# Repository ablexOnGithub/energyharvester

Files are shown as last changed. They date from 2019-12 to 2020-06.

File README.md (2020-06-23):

# lorawan_eharvester_node
hardware and code artefacts of lorawan energy harvester node

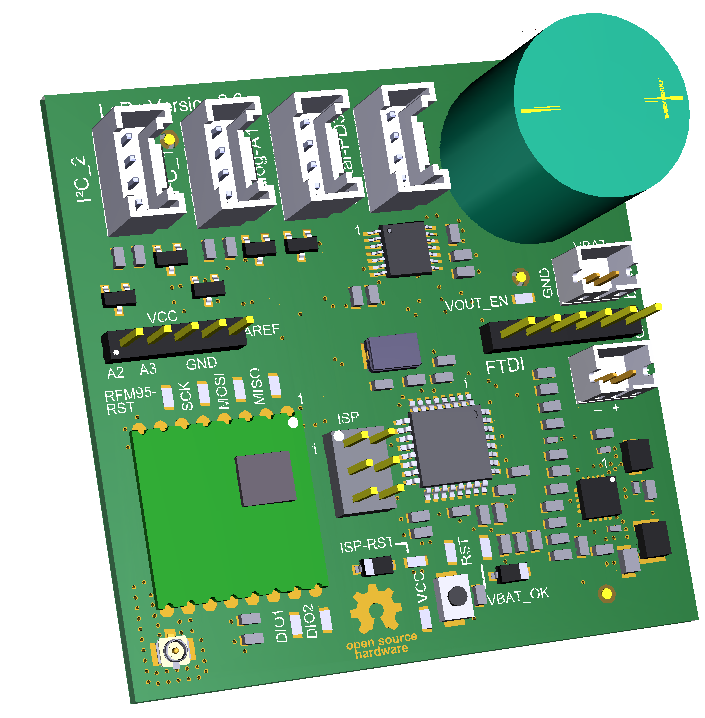
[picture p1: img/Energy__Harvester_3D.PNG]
3D view of harvester PCB


## Technical features
* AVR ATmega328PB
* RFM95 LoRaWAN-Modul 868MHz (replaceable with other market variants)
* TI BQ25570 Energy Harvester with MPPT, configured for solar power source
* 1F Supercap
* 2x Grove I2C sockets
* 1x Grove Analog socket
* 1x Grove Digital socket
* 1x JST PH socket for battery connection
* 1x JST PH socket for solar panel connection
* 1x FTDI connector for serial console and programming
* 1x u.FL socket for LoRa antenna
* Power supply can be configured for different battery types (LiPo, LiFePo or similar)
* Switchable Vcc for Grove connectors through CMOS switches
* ISP socket for AVR programming

## Sensor connections
In general all sensor sockets (Grove layout) have a switchable Vcc line. It is off by default and has to be enabled by corresponding GPIO lines.

## I2C
There are 2 hardware I2C ports in the 328PB. Arduino currently supports one out of the box (running as a 328P Arduino Pro Mini clone). The second I2C port is prepared for future use.

### Grove I2C 01
The SDA and SCL lines of the socket are connected to PC4 and PC5 accordingly.

__GPIO PD4 == High (1) activates Vcc__

When activating Vcc, additionally SDA and SCL are pulled high to Vcc via 10 kOhm resistors. 

### Grove I2C 02
The SDA1 and SCL1 lines of the socket are connected to PE0 and PE1 accordingly.

__GPIO PD5 == High (1) activates Vcc__

When activating Vcc, additionally SDA1 and SCL1 are pulled high to Vcc via 10 kOhm resistors.

## Grove Analog
The analog signal connected to the socket is fed into the ADC1 input of the AVR.

__GPIO PD6 == High (1) activates Vcc__

## Grove Digital
Vcc on the digital Grove socket is permanently supplied.

__GPIO PD3 == Data input for digital sensor__

## Energy harvesting power supply
The Energy Harvester integrates a harvesting power supply chip BQ25570 from Texas Instruments. It provides the 3.3V Vcc supply voltage for the AVR and attached sensors. It also provides the charging voltage for the batteries and the supercap. It also features MPPT (Maximum Power Point Tracking), to extract maximum energy from solar panels even in low light scenarios. Other power sources like thermal energy generators (TEG) can also be adapted as power source. 5.5V is the maximum allowed charge voltage level of the BQ25570. And the maximum input voltage of the power source is 5.1V. The allowed peak input power is 510mW, thus a solar cell for this energy harvester should be selected accordingly and cells > 0.5W seem not to be feasible. A better approach would be to use two 0.25W cells in parallel to adapt to the sun path by pointing into different directions. Then, bypass diodes might have to added to the solar cells.

Product page:
http://www.ti.com/product/BQ25570

## Configuration of battery type

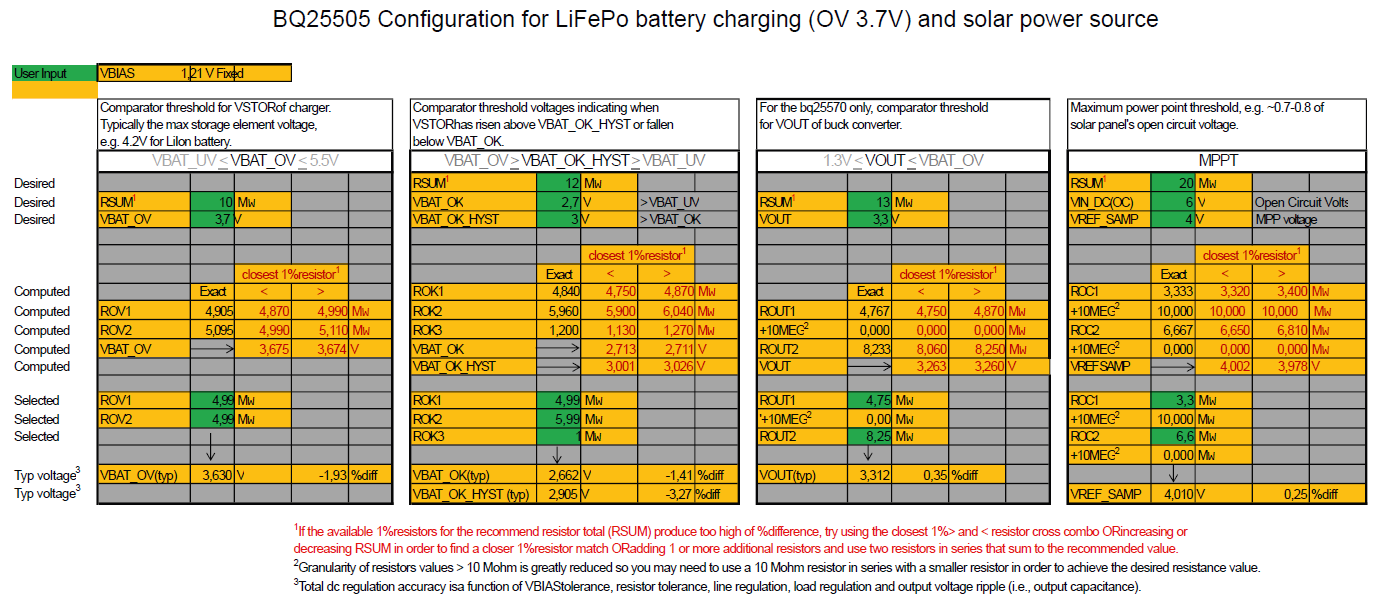
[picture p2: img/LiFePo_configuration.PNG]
Example of resistor configuration sheet


The image shows a resistor configuration sheet (example of LiFePo configuration), provided as a template by Texas Instruments. The sheet references the predecessor BQ25505, which provides the same configuration system with multiple resistors. All resistors are 1% 1/10W SMD parts in size 0603.

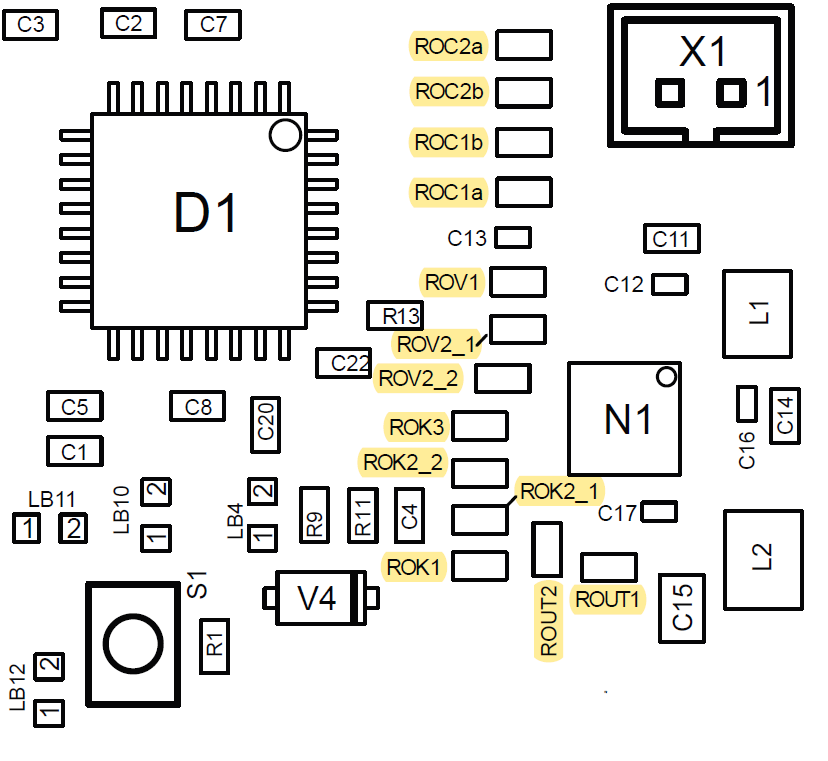
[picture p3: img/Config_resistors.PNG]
Location of configuration resistors on PCB


To configure the harvester for LiPo or LiFePo battery cells the corresponding resistors have to have the following values. This mainly adjusts the overvoltage level.

__Info for Supercap mode:__ I'm currently trying out a Vishay supercap with 90F capacity at 5V. This will not have a backup battery. Idea is to increase overvoltage level to 5V (instead of 4.2/3.6V), to have more headroom for the Buck converter to longer provide 3.3V to the sensor electronics. Hopefully this is a solution for sensors that really need stable 3.3V supply. The LiPo/LiFePo configurations are running until below 3V. This currently is an untested resistor configuration!!! 

Part 	| Li-Po cells | LiFePo cells	| Supercap mode 
--- | ---	| ---	| ---
ROK1 	| 4.99 MOhm	| 4.99 MOhm	| 4.22 MOhm
ROK2_1	| 3.3 MOhm	| 4.99 MOhm	| 4.02 MOhm
ROK2_2	| 4.02 MOhm	| 1 MOhm	| 3.3 MOhm
ROK3 	| 806 kOhm	| 1 MOhm	| 681 kOhm
ROV1	| 5.62 MOhm	| 4.99 MOhm	| 3.6 MOhm
ROV2_1	| 4.02 MOhm	| 4.02 MOhm	| 3.0 MOhm
ROV2_2  | 3.3 MOhm	| 1 MOhm	| 3.3 MOhm
ROC1a 	| 3.3 MOhm	| 3.3 MOhm	| 3.3 MOhm
ROC1b 	| 10 MOhm	| 10 MOhm	| 10 MOhm
ROC2a	| 1 MOhm	| 1 MOhm	| 1 MOhm
ROC2b 	| 5.6 MOhm	| 5.6 MOhm	| 5.6 MOhm

## Tracking of Vcc
Using a voltage divider Vcc is measured against the AVR internal reference voltage (1.1V, selected via Software, AVR reference "INTERNAL"). The corresponding voltage is fed into ADC0 of the AVR, to allow for a dynamic adjustment of the sleep interval, related to the actual Vcc voltage level. The lower Vcc the longer the sleep intervall to safe power. Vcc can only be measured, while analog Grove port is activated by __GPIO PD6 == High__.

# PCB Bring Up

## Test of Boost function
* Connect a 3V to 4V power supply with the solar connector X1, simulation a solar cell.
* Measure the open circuit voltage at the battery connector X2, which shall be the configured Overvoltage level
* After connecting a power supply it may take about 1 minute to charge the 1F supercap to the corresponding voltage level 4.2V, 3.6V or 5V
* Now connect a battery or a supercap, depending on build variant, that is compatible to the measured voltage level

## Test of Buck function
* Set __VOUT_EN__ active by bridging the corresponding jumper pads
* Measure voltage Vcc at 5-pin header and expect to see ca. 3.3V 
                                                                                                                        
## Programming of Arduino bootloader
* Set __VCC__ active by bridging the corresponding jumper pads
* Set __ISP_RST__ active by bridging the corresponding jumper pads
* Connect the ISP adapter (z.B. ATMEL  JTAGICE3) with the programming port
* Program a matching Arduino bootloader into the AVR     

## Fuse Bits

After programming the bootloader, we have to set the fuse bits to match the hardware features.

Fuse | Value
--- | ---
CFD | "CFD_DISABLED"
BODLEVEL | "DISABLED"
RSTDISBL | unset
DWEN | unset
SPIEN | set
WDTON | unset
EESAVE | set
BOOTSZ | "256W_3F00"
BOOTRST | set
CKDIV8 | unset
CKOUT | unset
SUT_CKSEL | "EXTXOSC_8MHZ_XX_16KCK_14CK_65MS"

These flags evaluate to the following bit masks:

__EXTENDED__= 0xF7
__HIGH__	= 0xD6
__LOW__		= 0xFF             

## Enable Reset lines
* Set __RESET__ active by bridging the corresponding jumper pads
	* This enables reset per switch and Arduino serial adapter (e.g. FTDI USB2COM)
* Set __VBAT_OK__ active by bridging the corresponding jumper pads
	* This enables reset by power good signal from bq25570 going low in case of battery undervoltage
 
## Test of serial connection 
* Connect a serial adapter
* Compile and download a simple Arduino sketch for the 328PB and check for valid debug output in serial console of Arduino
* This checks for a working serial port and a functioning bootloader

## Connecting RFM95 I/O
Bridge the remaining jumper pads for the LoRa module, which are __RFM95-RST__, __MISO__, __MOSI__, __SCK__, __DIO1__ and __DIO2__.

Now you can adjust the supplied test sketch in the ```/src``` folder by adding valid keys for your TTN application into, compile and download it to the harvester. In the serial console you will find debug output after restart, giving information on the LoRaWAN communication.

# Software

## Configuration of Arduino IDE
Avrdude has to be configured to ignore the changed chip ID of the AVR ATMega328PB when uploading a new Arduino sketch. This is done by adding a '-F' to the command line options of verbose mode for avrdude in Arduino's __platform.txt__ document. There are two lines to edit. After this activate "verbose"
mode for upload in the Arduino IDE preferences.
```
tools.avrdude.upload.params.verbose=-v -F
tools.avrdude.program.params.verbose=-v -F
```
### Libraries from Library manager inside Arduino IDE
The following libraries are needed to use the provided template sketch
* Low-Power by Rocket Scream Electronics (there are alot others with a similar name, please take this one)
* MCCI LoRaWAN lmic Library (tested with v3.0.99, currently the MCCI lmic version is the newest fork)

### Additional libraries
https://github.com/felias-fogg/SoftI2CMaster

### Board selection
Install the Arduino AVR Boards package and select __"Arduino Pro or Pro mini"__ as board. As processor select __"ATmega 328p (3.3V, 8MHz)"__. Now connect your FTDI TTL serial port and configure the port inside the IDE accordingly.                     

## Example sketch for Arduino
The example sketch soil_humidity_sensor_template.ino in the /src folder presents a template for building a first prototype of the Energy Harvester with a capacitive soil humidity sensor attached.

### Device and App configuration

# Energy sources

## Solar cells

### crystaline solar cells

### thin film solar cells

# Measurements

## Run and Sleep current
I made some test measurements with a Qoitech Otii source meter for sleep current of the energy harvester. These first measurements were done without attached external sensors, to see the theoretical minimum consumption of the node. It was measured at the battery port of the harvester and the supply was set to 3.2V, to simulate a LiFePo battery.

This is a recording of the system startup showing all power modes of the device. The peak current seems to be slightly above 60mA

Startup measurement of power consumption

A zoomed view of sleep current. The internal power consumption of the BQ25570 seems to be visible here. We got a __mean value of 3.9uA__ and a __maximum value of 30.1uA__ sleep current.

Zoom on sleep current

An even more detailed look into the energy consumption of the device when it wakes __every 8s__ and going to sleep directly again. 8s is the longest possible sleep duration of the AVR internal sleep timer. So every longer sleep period has to be implemented with a sequence of a multiple of 8s sleeps. The ingrease of energy consumption for this "useless" sleep/wakeup is about __2.36nWh per iteration__.

If you plan to use an external RTC to allow for longer sleep times and interrupt driven wake up, check if you RTC consumes less than the energy needed by a sequence of multiple 8s wake ups.

Energy consumption per wake up

# 3D printed parts
There are also 3D print parts that help mounting the harvester in rugged outdoor housings
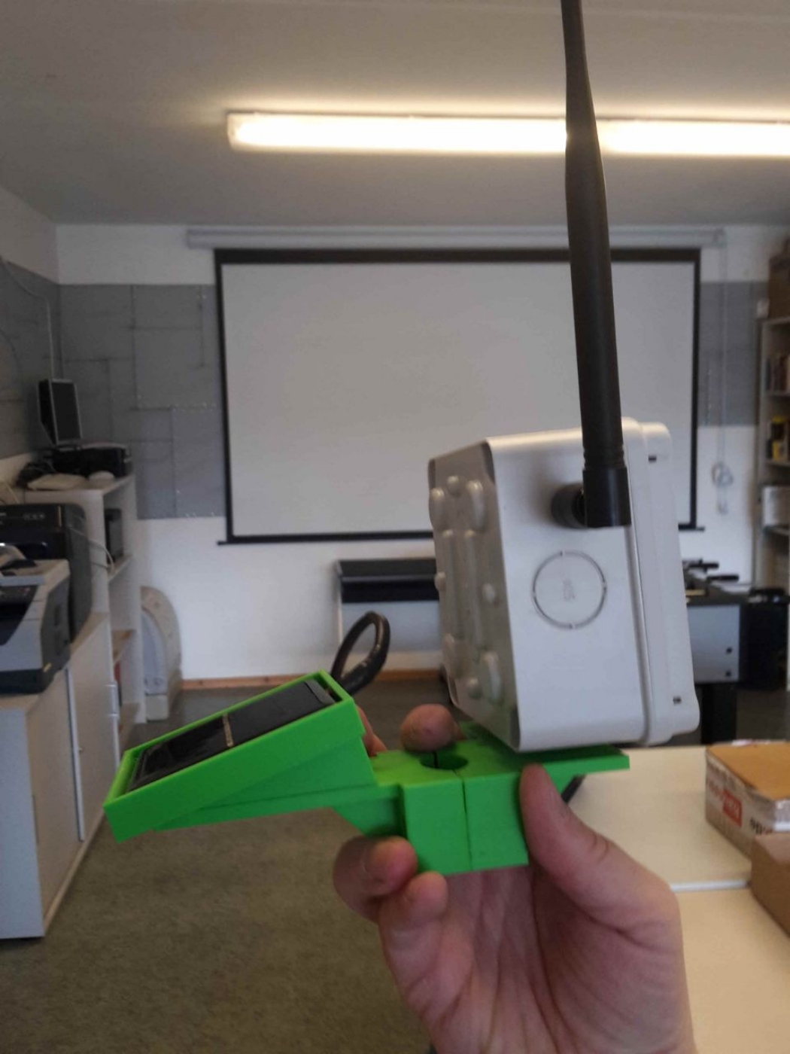
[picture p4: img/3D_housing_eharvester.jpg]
eharvester mount for outdoor housings


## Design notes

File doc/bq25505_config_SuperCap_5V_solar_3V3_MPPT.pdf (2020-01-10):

User Input | VBIAS | 1,21 | V
Fixed
Comparator threshold for VSTOR of charger. | Comparator threshold voltages indicating when | For the bq25570 only, comparator threshold | Maximum power point threshold, e.g. ~0.7-0.8 of
Typically the max storage element voltage, | VSTOR has risen above VBAT_OK_HYST or fallen | for VOUT of buck converter. | solar panel's open circuit voltage.
e.g. 4.2V for LiIon battery. | below VBAT_OK.
Desired | RSUM¹ | 12 | MW | RSUM¹ | 20 | MW
Desired | RSUM¹ | 10 | MW | VBAT_OK | 3,3 | V | > VBAT_UV | RSUM¹ | 13 | MW | VIN_DC(OC) | 6 | V | Open Circuit Volts
Desired | VBAT_OV | 5 | V | VBAT_OK_HYST | 3,5 | V | > VBAT_OK | VOUT | 3,3 | V | VREF_SAMP | 4 | V | MPP voltage
| | | | | | | Exact | < | > | | | | | | | | Exact | < | >
Computed | | Exact | < | > | | ROK1 | 4,149 | 4,120 | 4,220 | MW | | Exact | < | > | | ROC1 | 3,333 | 3,320 | 3,400 | MW
Computed | ROV1 | 3,630 | 3,570 | 3,650 | MW | ROK2 | 7,166 | 7,150 | 7,320 | MW | ROUT1 | 4,767 | 4,750 | 4,870 | MW | +10MEG² | 10,000 | 10,000 | 10,000 | MW
Computed | ROV2 | 6,370 | 6,340 | 6,490 | MW | ROK3 | 0,686 | 0,681 | 0,698 | MW | +10MEG² | 0,000 | 0,000 | 0,000 | MW | ROC2 | 6,667 | 6,650 | 6,810 | MW
Computed | VBAT_OV | | 5,038 | 5,042 | V | VBAT_OK | | 3,310 | 3,309 | V | ROUT2 | 8,233 | 8,060 | 8,250 | MW | +10MEG² | 0,000 | 0,000 | 0,000 | MW
Computed | | | | | | VBAT_OK_HYST | | 3,510 | 3,509 | V | VOUT | | 3,263 | 3,260 | V | VREF SAMP | | 4,002 | 3,978 | V
Selected | ROV1 | 3,6 | MW | ROK1 | 4,22 | MW | ROUT1 | 4,75 | MW | ROC1 | 3,3 | MW
Selected | ROV2 | 6,3 | MW | ROK2 | 7,32 | MW | '+10MEG² | 0,00 | MW | +10MEG² | 10,000 | MW
Selected | ROK3 | 0,681 | MW | ROUT2 | 8,25 | MW | ROC2 | 6,6 | MW
| | | | | | | | | | | | | | | | +10MEG² | 0,000 | MW
Typ voltage³ | VBAT_OV(typ) | 4,991 | V | -0,18 | % diff | VBAT_OK (typ) | 3,309 | V | 0,27 | % diff | VOUT(typ) | 3,312 | 0,35 | % diff
Typ voltage³ | VBAT_OK_HYST (typ) | 3,504 | V | 0,12 | % diff | VREF_SAMP | 4,010 | V | 0,25 | % diff

1
If the available 1% resistors for the recommend resistor total (RSUM) produce too high of % difference, try using the closest 1% > and < resistor cross combo OR increasing or decreasing RSUM in order to find a closer 1% resistor match OR adding 1 or more additional resistors and use two resistors in series that sum to the recommended value.
2Granularity of resistors values > 10 Mohm is greatly reduced so you may need to use a 10 Mohm resistor in series with a smaller resistor in order to achieve the desired resistance value.

3
Total dc regulation accuracy is a function of VBIAS tolerance, resistor tolerance, line regulation, load regulation and output voltage ripple (i.e., output capacitance).
VBAT_UV < VBAT_OV < 5.5V | VBAT_OV > VBAT_OK_HYST > VBAT_UV | 1.3V < VOUT < VBAT_OV | MPPT

closest 1% resistor¹

closest 1% resistor¹

closest 1% resistor¹

closest 1% resistor¹

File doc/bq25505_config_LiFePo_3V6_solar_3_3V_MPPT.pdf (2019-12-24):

User Input | VBIAS | 1,21 V Fixed
Comparator threshold for VSTORof charger. | Comparator threshold voltages indicating when | For the bq25570 only, comparator threshold | Maximum power point threshold, e.g. ~0.7-0.8 of
Typically the max storage element voltage, | VSTORhas risen above VBAT_OK_HYST or fallen | for VOUT of buck converter. | solar panel's open circuit voltage.
e.g. 4.2V for LiIon battery. | below VBAT_OK.
Desired | | | RSUM¹
12 | MW | RSUM¹
20 | MW
Desired | RSUM¹
10 | MW | VBAT_OK | 2,7 | V | >VBAT_UV | RSUM¹
13 | MW | VIN_DC(OC) | 6 | V | Open Circuit Volts
Desired | VBAT_OV | 3,7 V | VBAT_OK_HYST | 3 V | > VBAT_OK | VOUT | 3,3 V | VREF_SAMP | 4 V | MPP voltage
Exact | < | > | Exact | < | >
Computed | Exact | < | > | ROK1 | 4,840 | 4,750 | 4,870 | MW | Exact | < | > | ROC1 | 3,333 | 3,320 | 3,400 | MW
Computed | ROV1 | 4,905 | 4,870 | 4,990 | MW | ROK2 | 5,960 | 5,900 | 6,040 | MW | ROUT1 | 4,767 | 4,750 | 4,870 | MW | +10MEG²
10,000 | 10,000 | 10,000 | MW
Computed | ROV2 | 5,095 | 4,990 | 5,110 | MW | ROK3 | 1,200 | 1,130 | 1,270 | MW | +10MEG²
0,000 | 0,000 | 0,000 | MW | ROC2 | 6,667 | 6,650 | 6,810 | MW
Computed | VBAT_OV | 3,675 | 3,674 V | VBAT_OK | 2,713 | 2,711 | V | ROUT2 | 8,233 | 8,060 | 8,250 | MW | +10MEG²
0,000 | 0,000 | 0,000 | MW
Computed | VBAT_OK_HYST | 3,001 | 3,026 V | VOUT | 3,263 | 3,260 V | VREFSAMP | 4,002 | 3,978 V
Selected | ROV1 | 4,99 MW | ROK1 | 4,99 | MW | ROUT1 | 4,75 | MW | ROC1 | 3,3 | MW
Selected | ROV2 | 4,99 MW | ROK2 | 5,99 | MW | '+10MEG²
0,00 | MW | +10MEG²
10,000 | MW
Selected | ROK3 | 1 MW | ROUT2 | 8,25 | MW | ROC2 | 6,6 | MW
+10MEG²
0,000 | MW
Typ voltage³ | VBAT_OV(typ) | 3,630 | V | -1,93 | %diff | VBAT_OK(typ) | 2,662 | V | -1,41 | %diff | VOUT(typ) | 3,312 | 0,35 | %diff
Typ voltage³
VBAT_OK_HYST (typ) | 2,905 V | -3,27 %diff | VREF_SAMP | 4,010 V | 0,25 | %diff

1
If the available 1%resistors for the recommend resistor total (RSUM) produce too high of %difference, try using the closest 1%> and < resistor cross combo ORincreasing or
decreasing RSUM in order to find a closer 1%resistor match ORadding 1 or more additional resistors and use two resistors in series that sum to the recommended value.
2Granularity of resistors values > 10 Mohm is greatly reduced so you may need to use a 10 Mohm resistor in series with a smaller resistor in order to achieve the desired resistance value.

3
Total dc regulation accuracy isa function of VBIAStolerance, resistor tolerance, line regulation, load regulation and output voltage ripple (i.e., output capacitance).
VBAT_UV<VBAT_OV<5.5V | VBAT_OV>VBAT_OK_HYST>VBAT_UV | 1.3V<VOUT<VBAT_OV | MPPT

closest 1%resistor¹

closest 1%resistor¹

closest 1%resistor¹

closest 1%resistor¹

# BQ25505 Configuration for LiFePo battery charging (OV 3.7V) and solar power source

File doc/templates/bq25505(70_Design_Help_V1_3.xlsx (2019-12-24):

User Input | VBIAS | 1.21 | V
Fixed
 | Comparator threshold for VSTOR of charger. |  |  |  |  | Comparator threshold voltages indicating when |  |  |  |  | For the bq25570 only, comparator threshold |  |  |  |  | Maximum power point threshold, e.g. ~0.7-0.8 of
 | Typically the max storage element voltage, |  |  |  |  | VSTOR has risen above VBAT_OK_HYST or fallen |  |  |  |  | for VOUT of buck converter. |  |  |  |  | solar panel's open circuit voltage.
 | e.g. 4.2V for LiIon battery. |  |  |  |  | below VBAT_OK.
 | VBAT_UV < VBAT_OV < 5.5V |  |  |  |  | VBAT_OV > VBAT_OK_HYST > VBAT_UV |  |  |  |  | 1.3V < VOUT < VBAT_OV |  |  |  |  | MPPT
Desired |  |  |  |  |  | RSUM1 | 13 | MW |  |  |  |  |  |  |  | RSUM1 | 20 | MW
Desired | RSUM1 | 13 | MW |  |  | VBAT_OK | 2.8 | V | > VBAT_UV |  | RSUM1 | 13 | MW |  |  | VIN_DC(OC) | 1 | V | Open Circuit Volts
Desired | VBAT_OV | 4.2 | V |  |  | VBAT_OK_HYST | 3.1 | V | > VBAT_OK |  | VOUT | 1.3 | V |  |  | VREF_SAMP | 0.9 | V | MPP voltage
 |  |  |  |  |  |  |  | closest 1% resistor1 |  |  |  |  |  |  |  |  |  | closest 1% resistor1
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

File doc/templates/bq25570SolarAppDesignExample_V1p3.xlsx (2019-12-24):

User Input
Computed/Fixed
 |  |  | VSTOR nominal | 3.00 | V |  |  |  |  | VBAT_UV < VSTOR nominal <= VBAT_OV
System Loads | VOUT (V) | IOUT (mA) | Est Buck Effcy per datasheet | ISTOR = (VOUTxIOUT) / (VSTORnom x Effcy) (mA) | Mode Duration (how long?) (s) | Mode Period (how often?) (s) | Mode Hours / Day = 24 hours x duration/ period | mAHr / Day = ISTOR X Mode Hrs / Day | mWHr / Day = VSTOR x mAHr / Day
Active Mode 1 - bq25570 VOUT | 1.800 | 49.500 | 0.930 | 31.935
Active Mode 1 - bq25570 VSTOR |  |  |  | 8.000 |  |  |  |  |  | Direct loading on VSTOR
Totals for Active Mode 1 |  |  |  | 39.935 | 0.040 | 60.000 | 0.016 | 0.639 | 1.917
Active Mode 2 - bq25570 VOUT | 1.800 | 6.500 | 0.850 | 4.588 |  |  |  |  |  | If only one active mode, enter 0 for IOUT.
Active Mode 2 - bq25570 VSTOR |  |  |  | 5.500 |  |  |  |  |  | If only one active mode, enter 0 for ISTOR.
Totals for Active Mode 2 |  |  |  | 10.088 | 0.125 | 60.000 | 0.050 | 0.504 | 1.513
Sleep Mode - bq25570 VSTOR (1.8V rail off) |  |  |  | 0.100 |  |  | 23.934 | 2.393 | 7.180 | Idle mode hours / day = 24 minus active mode hours / day
bq25570 quiescent current + storage element leakage current |  |  |  | 0.001 |  |  | 24.000 | 0.024 | 0.072 | Storage element leaks all the time.
 | Total mAHr / day consumed |  |  |  |  |  |  | 3.561 | mAHr / day
 | Multiply by max consec dark days (e.g. not charging when overcast or raining) |  |  |  |  |  |  | 2.000 | days / week
 | Recommended minimum battery capacity |  |  |  |  |  |  | 7.122 | mAHr
 | -OR-
 | Mininum super capacitor voltage |  |  |  |  |  |  | 2.500 | V | VBAT_UV = 2.0V > Min super capacitor > VSTOR nominal
 | Maximum super capacitor voltage |  |  |  |  |  |  | 4.000 | V | VSTOR nominal < Max super capacitor voltage <= VBAT_OV
 | Recommended minimum super capacitance |  |  |  |  |  |  | 15.777 | F | Min Bat Capacity / 1000 x 3600s/hr x VSTORNOM = 1/2 x CSUPER x (Vmax2 - Vmin2)
 |  | Total mWHr / day consumed |  |  |  |  |  |  | 10.682 | mWHr / day
 |  | Multiply by operating days per week |  |  |  |  |  |  | 7.000 | days / week
 |  | Total mWHr /week required for system operation for the week |  |  |  |  |  |  | 74.776 | mWHr / week
 |  | Divide by charging days per week |  |  |  |  |  |  | 5.000 | days / week | Operating days minus max consecutive dark days
 |  | Total mWHr / day required to be collected by solar panel during charging days |  |  |  |  |  |  | 14.955 | mWHr / day | Total 7-day power must be collected during 5 charging days
 |  | Divide by charging hours / day |  |  |  |  |  |  | 8.000 | hours / day | i.e., includes excess energy for charging the battery
 |  | Instantaneous power required from the solar panel |  |  |  |  |  |  | 1.869 | mW
 |  |  | Divide by low estimate of bq25570 efficiency per datasheet |  |  |  |  |  | 0.800
 |  |  | Minimum input power required for system operation |  |  |  |  |  | 2.337 | mW
 |  |  |  | Divide by panel power per panel datasheet |  |  |  |  | 8.000 | mW/cm2 | Use power from lowest expected light level
 |  |  |  | Minimum solar panel area required |  |  |  |  | 0.292 | cm2

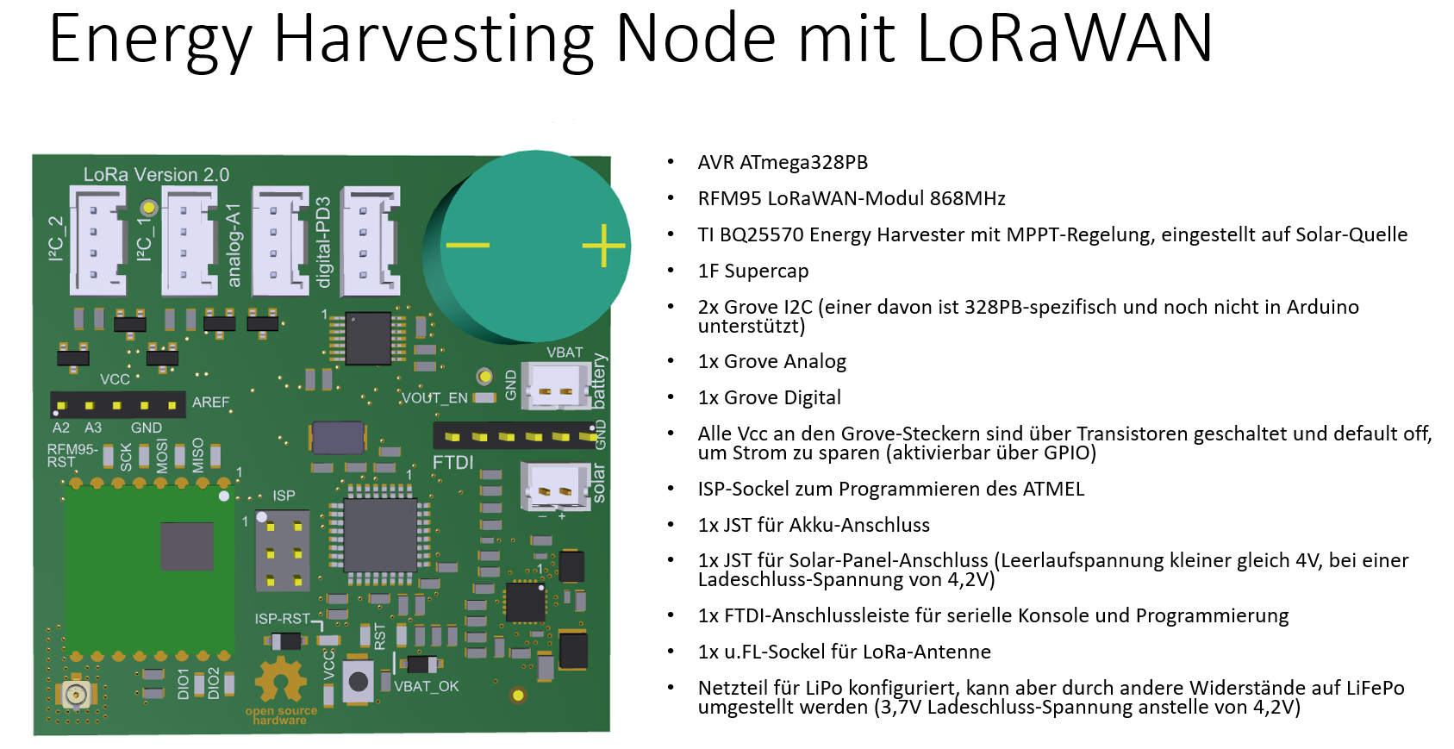
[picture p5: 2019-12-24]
doc/Energy__Harvester_Node.PNG

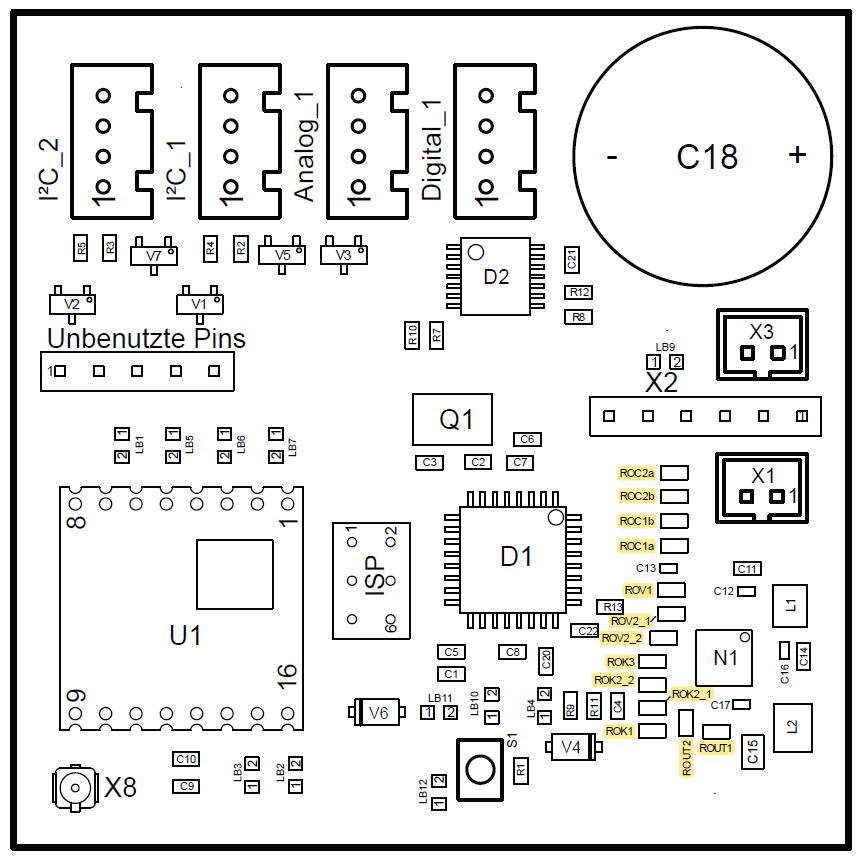
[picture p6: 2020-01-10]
img/PCB_Placement.PNG

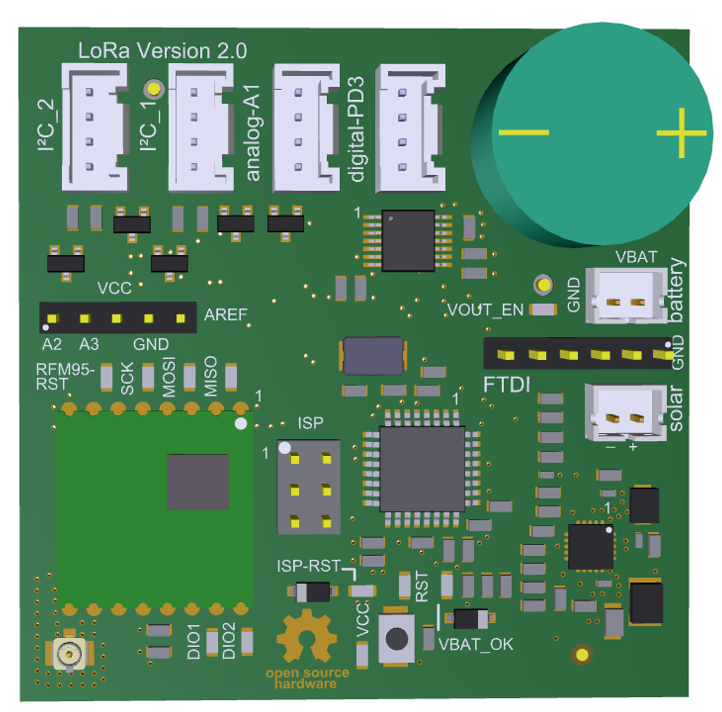
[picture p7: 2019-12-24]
img/Energy__Harvester_Top.PNG

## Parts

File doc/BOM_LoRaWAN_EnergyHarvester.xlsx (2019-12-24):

Manuf. Part Number | Manufacturer | Seeed OPL | Digi-Key Part. No. | Customer reference | Reference designator | Quantity | Pcs price | Sum | Description
RT0603FRE071ML | Yageo | RC0603FR-071ML | YAG5944CT-ND | 0603_reflow | ROC2a | 1 | 0,09000 | 0,27 € | RES SMD 1M OHM 1% 1/10W 0603
CRCW06035M62FKEA | Yageo | RC0603FR-075M6L | 541-5.62MHCT-ND | 0603_reflow | ROC2b | 1 | 0,09000 | 0,27 € | RES SMD 5.62M OHM 1% 1/10W 0603
CRCW06034M99FKEA | Yageo | RC0603FR-074M99L | 541-4.99MHCT-ND | 0603_reflow | ROK1 | 1 | 0,09000 | 0,36 € | RES SMD 4.99M OHM 1% 1/10W 0603
CRCW06034M02FKEA | Yageo | RC0603FR-074M02L | 541-4.02MHCT-ND |  | ROV2_1 | 1 | 0,09000 | 0,18 € | RES SMD 4.02M OHM 1% 1/10W 0603
CRGCQ0603J10M | Yageo | RC0603FR-0710ML | A130115CT-ND |  | ROC1a | 1 | 0,09000 | 0,09 € | CRGCQ 0603 10M 5%
CRCW06033M30FKEA | Yageo | RC0603FR-073M3L | 541-3.30MHCT-ND |  | ROC1b | 1 | 0,09000 | 0,27 € | RES SMD 3.3M OHM 1% 1/10W 0603
RC0603FR-074M75L | Yageo | RC0603FR-074M7L | 311-4.75MHRCT-ND | 0603_reflow | ROUT1 | 1 | 0,09000 | 0,09 € | RES SMD 4.75M OHM 1% 1/10W 0603
CRCW06038M25FKEA | Yageo | RC0603FR-078M2L | 541-8.25MHCT-ND | 0603_reflow | ROUT2 | 1 | 0,09000 | 0,09 € | RES SMD 8.25M OHM 1% 1/10W 0603
RC0603FR-071K02L | Yageo | RC0603FR-071K02L | 311-1.02KHRCT-ND | 0603 1k2 | R11 | 1 | 0,09000 | 0,09 € | RES SMD 1.02K OHM 1% 1/10W 0603
CRCW0603422RFKEA | Yageo | RC0603FR-07422RL | 541-422HCT-ND | 0603_reflow | R9 | 1 | 0,09000 | 0,09 € | RES SMD 422 OHM 1% 1/10W 0603
CRCW060310K0FKEA | Yageo | RC0603FR-0710KL | 541-10.0KHCT-ND | 0603_reflow | R1, R2, R3, R4, R5, R7, R8, R10, R12 | 9 | 0,09000 | 0,81 € | RES SMD 10K OHM 1% 1/10W 0603
CRG0603J100R | Yageo | RC0603FR-07100RL | A126330CT-ND | 0603_reflow | R13 | 1 | 0,09000 | 0,09 € | RES SMD 100 OHM 5% 1/10W 0603
C0402C103K5RACTU | Yageo | CC0402KRX7R9BB103 | 399-3066-1-ND | 0402_reflow | C13 | 1 | 0,09000 | 0,09 € | CAP CER 10000PF 50V X7R 0402
CL05B104KP5NNNC | Yageo | CC0402KRX7R6BB104 | 1276-1002-1-ND | 0402_reflow | C12, C16, C17 | 3 | 0,09000 | 0,27 € | CAP CER 0.1UF 10V X7R 0402
LMK107B7105KA-T | Yageo | CC0603KRX7R7BB105 | 587-1242-1-ND | 0603_reflow | C1, C6, C9 | 3 | 0,09000 | 0,27 € | CAP CER 1UF 10V X7R 0603
JMK107BJ475KA-T | Yageo | CC0603KRX5R5BB475 | 587-1785-1-ND | 0603_reflow | C11, C14 | 2 | 0,10000 | 0,20 € | CAP CER 4.7UF 6.3V X5R 0603
VJ0603A180JXACW1BC | Yageo | CC0603JRNPO9BN180 | 720-1524-1-ND | 0603_reflow | C2, C3 | 2 | 0,10000 | 0,20 € | CAP CER 18PF 50V C0G/NP0 0603
VJ0603Y104KXJCW1BC | Yageo | CC0603KRX7R9BB104 | 720-1532-1-ND | 0603_reflow | C4, C5, C7, C8, C10, C20, C21, C22 | 8 | 0,17000 | 1,36 € | CAP CER 0.1UF 16V X7R 0603
JMK212BJ226KG-T | Yageo | CC0805KKX5R5BB226 | 587-1468-1-ND | 0805_h1.25_reflow | C15 | 1 | 0,54000 | 0,54 € | CAP CER 22UF 6.3V X5R 0805
BRL3225T100K | TDK | NLCV32T-100K-PFR | 587-2167-1-ND | zld_3.2x2.5x1.7 | L2 | 1 | 0,25000 | 0,25 € | FIXED IND 10UH 700MA 420 MOHM
NLV25T-220J-EF | TDK | NLV25T-220J-PF | 445-16468-1-ND | zld_2.5x2x1.6 | L1 | 1 | 0,25000 | 0,25 € | FIXED IND 22UH 125MA 5.5 OHM SMD
BAT46W-E3-08 | JCET | 304020012 | BAT46W-E3-08CT-ND | SOD123_reflow | V4, V6 | 2 | 0,35000 | 0,70 € | DIODE SCHOTTKY 100V 150MA SOD123
BSS84 | DIODES | BSS84-7-F | BSS84CT-ND | SOT23_reflow | V1, V2, V3, V5, V7 | 5 | 0,31000 | 1,55 € | MOSFET P-CH 50V 130MA SOT-23
ABM3-8.000MHZ-D2Y-T | Abracon LLC | ABM3-8.000MHZ-D2Y-T | 535-10630-1-ND | GQZ_HCX_5FA_5.0x3.2 | Q1 | 1 | 1,04000 | 1,04 € | CRYSTAL 8.0000MHZ 18PF SMD
1909763-1 | TE Connectivity AMP Connectors | U.FL-R-SMT-1（80) | A118077CT-ND | BU_2p_90g_bnc_U.FL-R-SMT-1_HIROSE | X8 | 1 | 0,45000 | 0,45 € | CONN UMCC JACK STR 50OHM SMD
ATMEGA328PB-AUR | Microchip Technology | ATMEGA328PB-AU | ATMEGA328PB-AURCT-ND | ATMEGA328PB | D1 | 1 | 1,33000 | 1,33 € | IC MCU 8BIT 32KB FLASH 32TQFP
MC74LCX14DTR2G | ON Semiconductor | 74HC04PW,118 | MC74LCX14DTR2GOSCT-ND | TSSOP14_rm0.65 | D2 | 1 | 0,37000 | 0,37 € | IC INVERTER SCHMITT 6CH 14TSSOP
BQ25570RGRT | Texas Instruments | BQ25570RGRT | 296-37014-1-ND | QFN20_3.65x3.65_RM0.5_EXPAD | N1 | 1 | 7,22000 | 7,22 € | IC ENERGY HARV CTRLR BATT 20VQFN
KMR241NG ULC LFS |  | TD-1183SN-A3N-D1R | CKN10285CT-ND | ZST_SKRKAHE010 | S1 | 1 | 0,53000 | 0,53 € | SWITCH TACTILE SPST-NO 0.05A 32V
LiPo-Configuration Resistors
CRCW06034M02FKEA | Yageo | RC0603FR-074M02L | 541-4.02MHCT-ND |  | ROK2_2_LiPo | 1 | 0,09000 | 0,18 € | RES SMD 4.02M OHM 1% 1/10W 0603
RC0603FR-07806KL | Yageo | RC0603FR-07806KL | 311-806KHRCT-ND | 0603_reflow | ROK3_LiPo | 1 | 0,09000 | 0,09 € | RES SMD 806K OHM 1% 1/10W 0603
CRCW06033M30FKEA | Yageo | RC0603FR-073M3L | 541-3.30MHCT-ND |  | ROV2_2_LiPo, ROK2_1_LiPo | 2 | 0,09000 | 0,27 € | RES SMD 3.3M OHM 1% 1/10W 0603
CRCW06035M62FKEA | Yageo | RC0603FR-075M6L | 541-5.62MHCT-ND | 0603_reflow | ROV1_LiPo | 1 | 0,09000 | 0,27 € | RES SMD 5.62M OHM 1% 1/10W 0603
LiFePo-Configuration Resistors
RC0603FR-07806KL | Yageo | RC0603FR-07806KL | 311-806KHRCT-ND | 0603_reflow | ROV2_2_LiFePo | 1 | 0,09000 | 0,09 € | RES SMD 806K OHM 1% 1/10W 0603
CRCW06034M99FKEA | Vishay Dale | RC0603FR-074M99L | 541-4.99MHCT-ND | 0603_reflow | ROV1_LiFePo, ROK_2_1_LiFePo | 2 | 0,09000 | 0,36 € | RES SMD 4.99M OHM 1% 1/10W 0603
RT0603FRE071ML | Yageo | RC0603FR-071ML | YAG5944CT-ND | 0603_reflow | ROK2_2_LiFePo, ROK3_LiFePo | 2 | 0,09000 | 0,27 € | RES SMD 1M OHM 1% 1/10W 0603
THT parts:
FG0H105ZF | KEMET |  | 399-10805-ND | ra_d17_rm5.08_h19 | C18 | 1 | 3,56000 | 3,56 € | CAP 1F -20% +80% 5.5V T/H
B2B-PH-K-S(LF)(SN) | JST Sales America Inc. |  | 455-1704-ND | ST_2p_1r_B2B-PH-K-S_rm2 | X1, X3 | 2 | 0,15000 | 0,30 € | CONN HEADER VERT 2POS 2MM
61300611121 | Würth Elektronik |  | 732-5319-ND | ST_6p_1r_180G_RM2.54 | X2 | 1 | 0,32000 | 0,32 € | CONN HEADER VERT 6POS 2.54MM
M20-9980345 | Harwin Inc. |  | 952-2120-ND | ST_6p_2r_180g_rm2.54 | ISP | 1 | 0,25000 | 0,25 € | CONN HEADER VERT 6POS 2.54MM
61300511121 | Würth Elektronik |  | 732-5318-ND | ST_5p_1r_180G_rm2.54_h8.2 | Unbenutzte Pins | 1 | 0,25000 | 0,25 € | CONN HEADER VERT 5POS 2.54MM
110990030 | Seeed Technology Co., Ltd |  | 1597-1082-ND | Grove socket 4pin | Analog_1, Digital_1, I²C_1, I²C_2 | 1 | 1,39000 | 1,39 € | GROVE 2MM 4PIN CONN 10PACK
109990166 | Seeed Technology Co., Ltd |  | 1597-1488-ND | RFM95_Funkmodul_liegend | U1 | 1 | 6,45000 | 6,45 € | RFM95 ULTRA-LONG RANGE TRANSCEIV

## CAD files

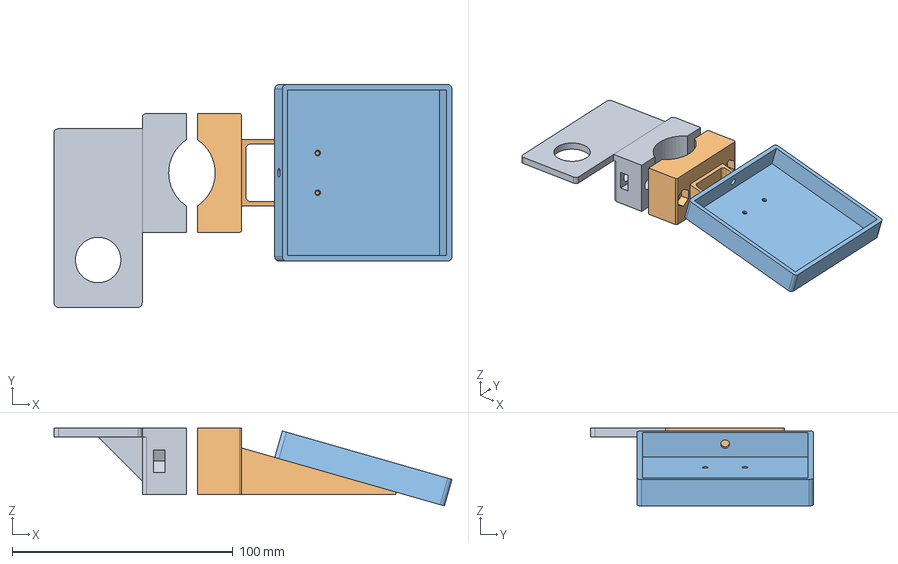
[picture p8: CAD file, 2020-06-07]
3Ddata/v2/freecad/energy_harvester_mastbefestigung.FCStd
180.4 x 101.0 x 35.3 mm
encloser_halter_v2_001
solar_halter_v2_001
solar_wanne_v2_001

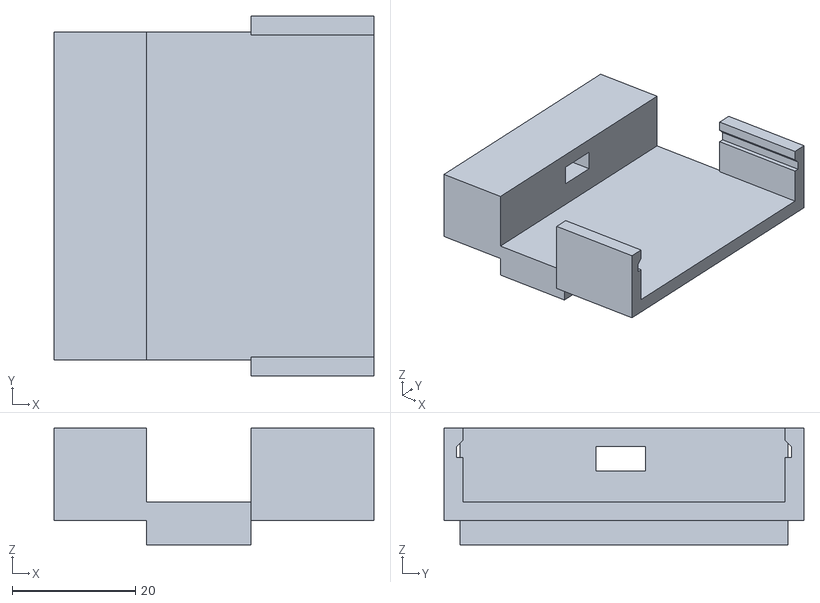
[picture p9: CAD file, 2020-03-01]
3Ddata/v2/stl/eharvester_mount.stl
52.0 x 58.5 x 19.0

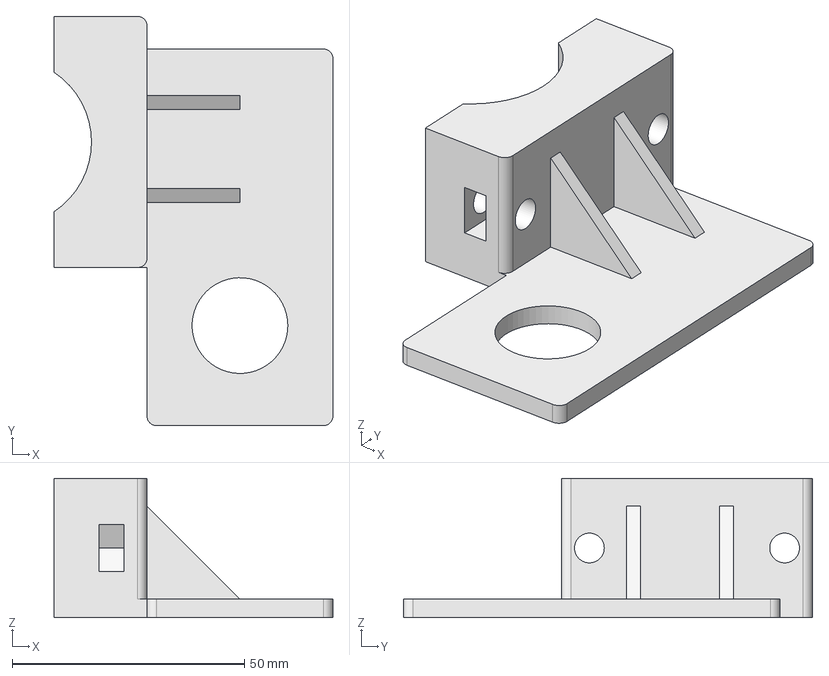
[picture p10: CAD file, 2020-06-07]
3Ddata/v2/freecad/encloser_halter_v2.FCStd
60.0 x 88.0 x 30.0 mm

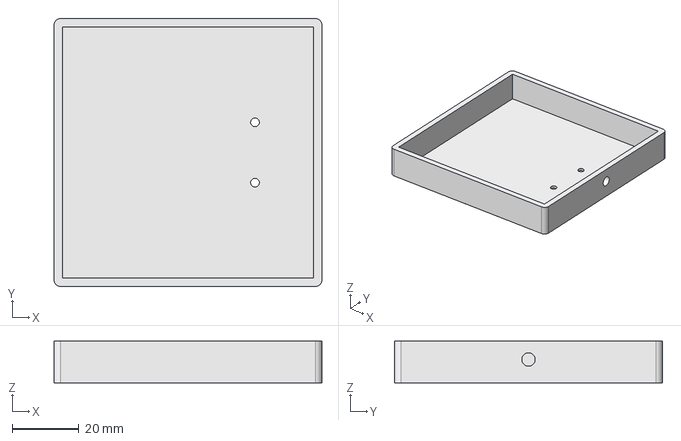
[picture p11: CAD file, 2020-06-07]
3Ddata/v2/freecad/solar_wanne_v2.FCStd
80.0 x 80.0 x 12.5 mm

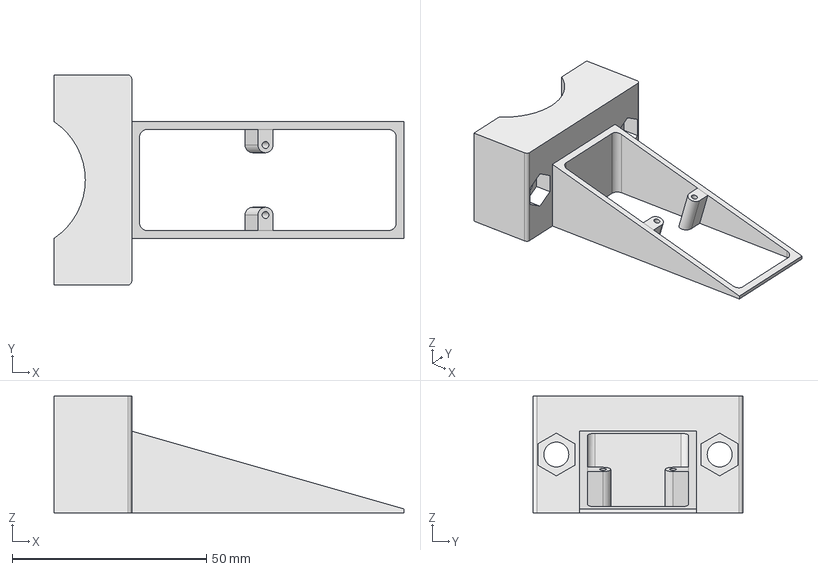
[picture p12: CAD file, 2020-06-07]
3Ddata/v2/freecad/solar_halter_v2.FCStd
90.0 x 54.0 x 30.0 mm

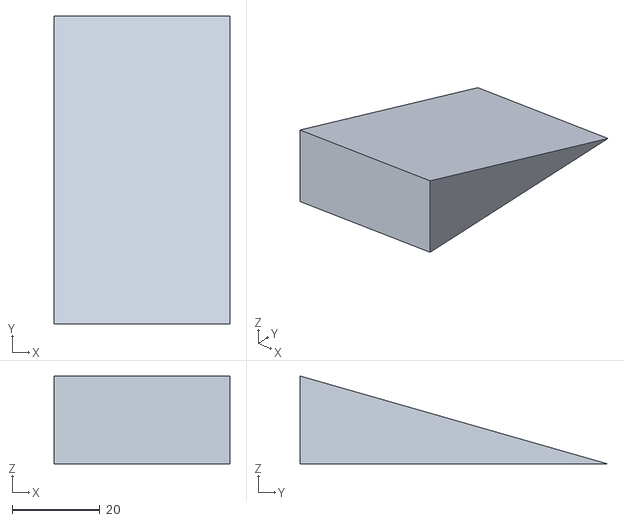
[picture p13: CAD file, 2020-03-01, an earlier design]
3Ddata/v1/stl/solar_mount2.stl
40.0 x 70.0 x 20.0

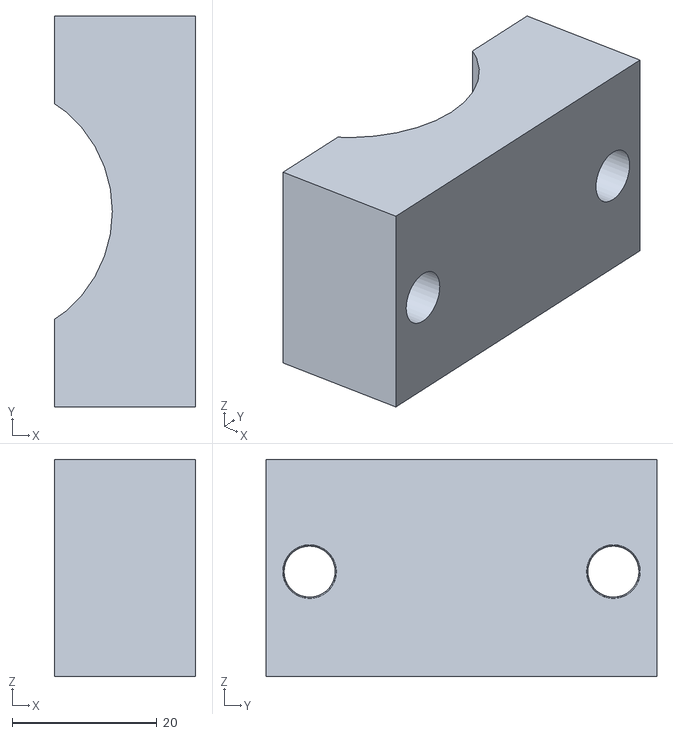
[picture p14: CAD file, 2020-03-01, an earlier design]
3Ddata/v1/stl/enclosure_back_mount.stl
19.5 x 54.0 x 30.0

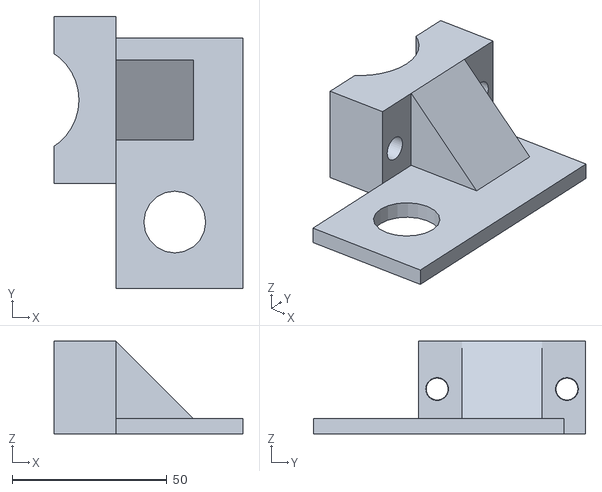
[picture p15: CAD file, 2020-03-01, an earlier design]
3Ddata/v1/stl/enclosure_groundmount.stl
61.0 x 88.0 x 30.0

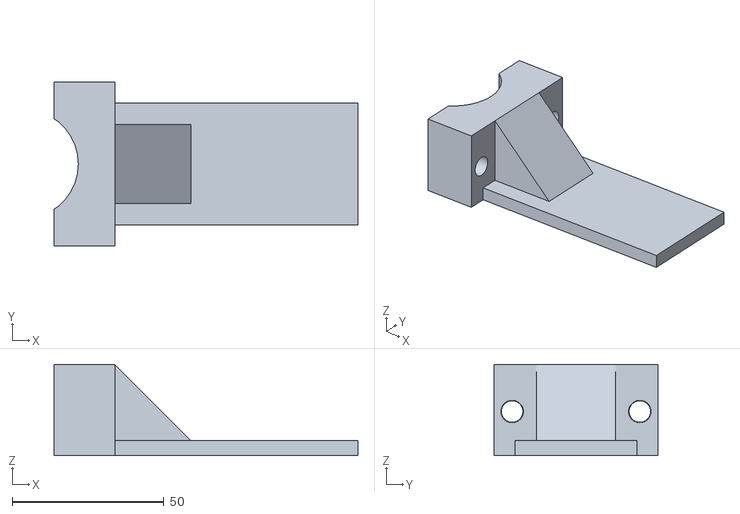
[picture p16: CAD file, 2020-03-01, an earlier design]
3Ddata/v1/stl/solar_mount3.stl
100.0 x 54.0 x 30.0

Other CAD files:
3Ddata/v1/stl/Solar_mount1.stl
3Ddata/v2/stl/encloser_halter_v2.stl
3Ddata/v2/stl/solar_halter_v2.stl
3Ddata/v2/stl/solar_wanne_v2.stl

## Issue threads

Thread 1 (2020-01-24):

VIN_DC on analog input

msei, 2020-01-24:
It might be good to have a sense of what's available at the source. This way a more informed decision could be made when it comes to scheduling work or sleep.
This could also be used as a primitive light sensor.

Hence I propose a switched voltage divider between VIN_DC and an analog pin on the MCU.

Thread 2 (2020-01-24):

Add non-volatile storage

msei, 2020-01-24:
State cannot be expected to survive a reset and write cycles to EEPROM are limited. It is also more efficient to store FCnt and other temporary state from LMIC rather than going through OTTA every time or using ABP and ignoring FCnt. Therefor the addition of a non-volatile storage is suggested like the [MB85RS64VPNF](https://www.digikey.de/product-detail/de/fujitsu-electronics-america-inc/MB85RS64VPNF-G-JNERE1/865-1260-1-ND/4022676)

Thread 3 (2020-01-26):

Reduce time to VSTOR_CHGEN

msei, 2020-01-26:
Supercap version

Having the storage element discharged, it takes a long time to reach VSTOR_CHGEN and thus entering a significantly more efficient mode of operation (~2h with Cstore 1F, a large 5V PV module on overcast conditions)

In this case the datasheet suggests a PFET controlled by an inverted VBAT_OK signal be added between the storage element and VBAT.

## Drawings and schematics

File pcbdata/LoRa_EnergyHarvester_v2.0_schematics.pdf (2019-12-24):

1 | 2 | 3 | 4 | 5 | 6 | 7 | 8

A

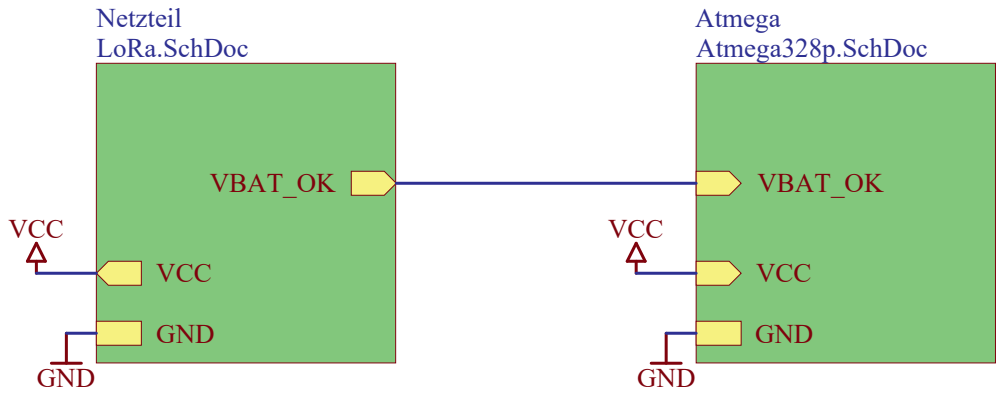
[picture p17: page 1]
Datum; Name; Änd.Nr.; gepr.; Zeichn.-Nr.; Maßstab; Blatt; LoRa; Benennung; Schaltungsteil; Block.SchDoc; LoRa Version 2.0; GND; VCC; VBAT_OK; Netzteil LoRa.SchDoc; Atmega Atmega328p.SchDoc

A

A

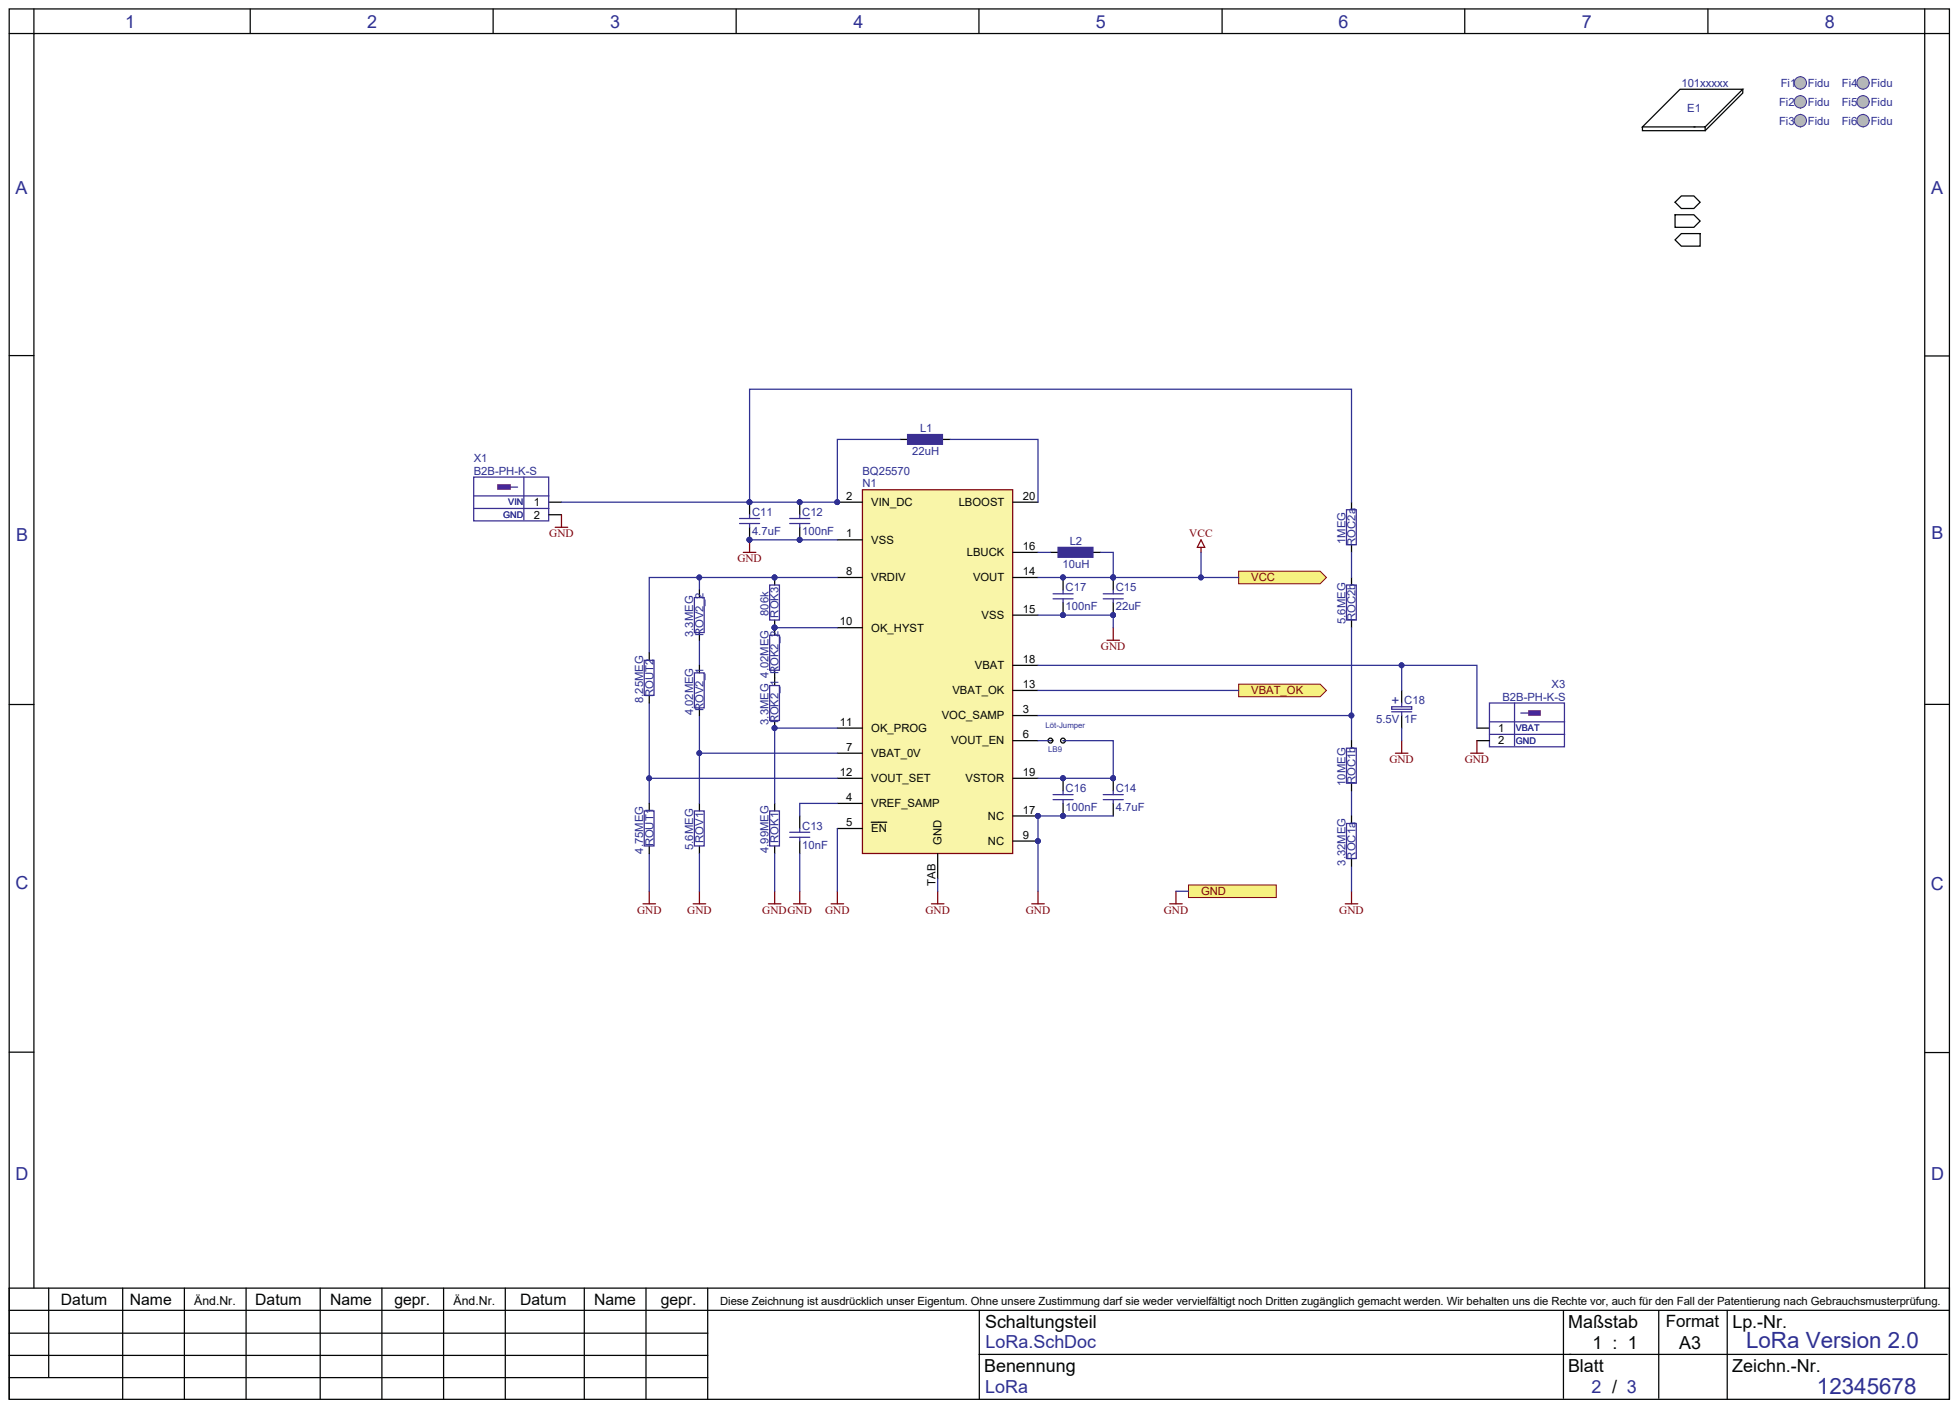
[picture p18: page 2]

GND ¹MEG ROC²a 3.32MEG ROC¹a 10MEG ROC¹b

A

A

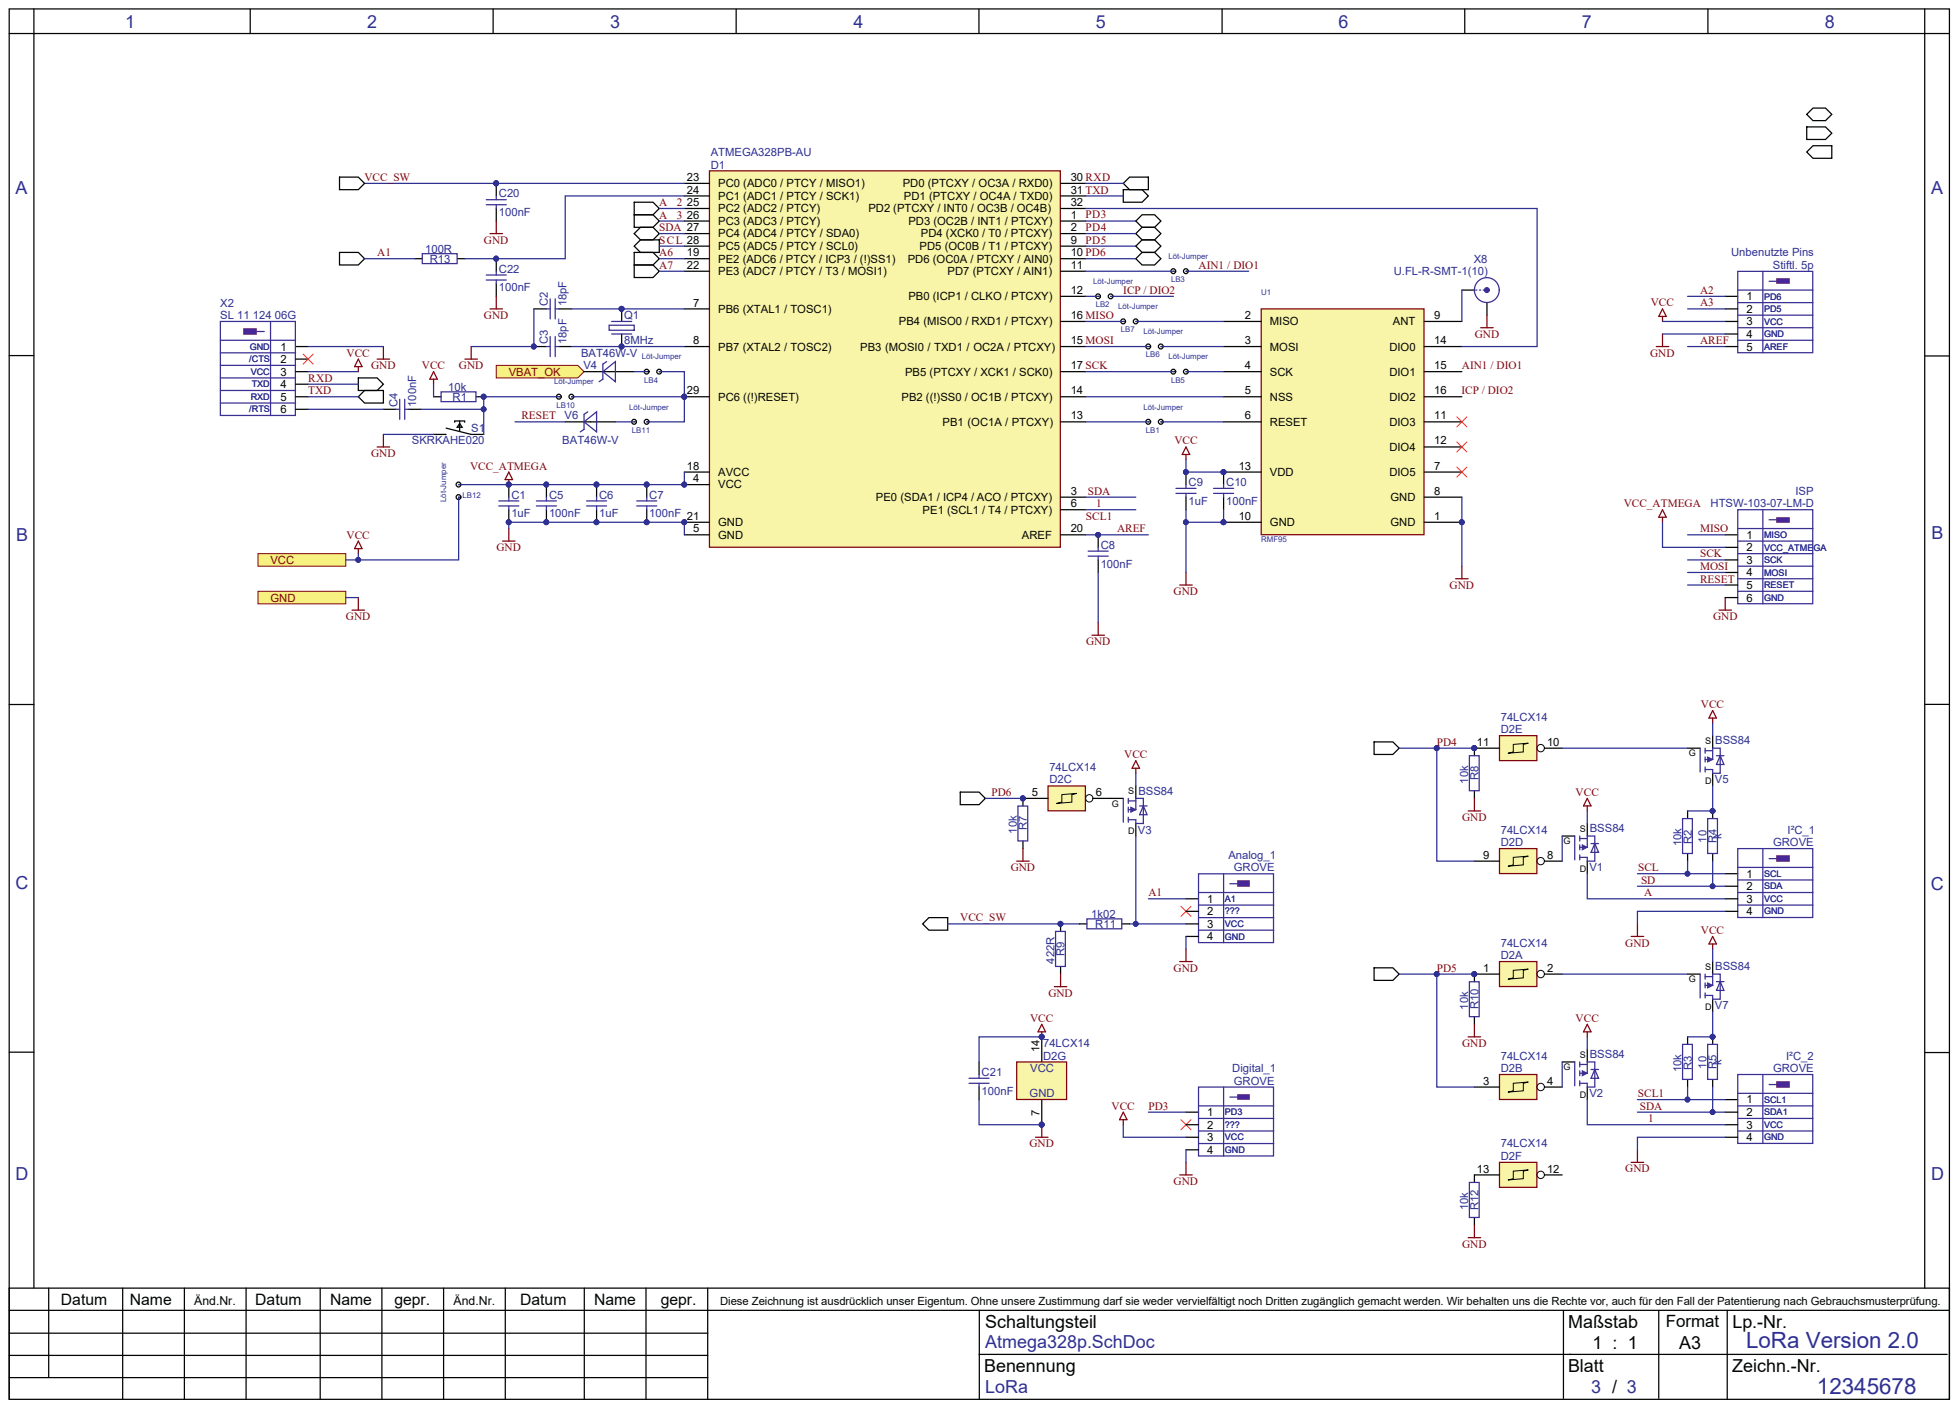
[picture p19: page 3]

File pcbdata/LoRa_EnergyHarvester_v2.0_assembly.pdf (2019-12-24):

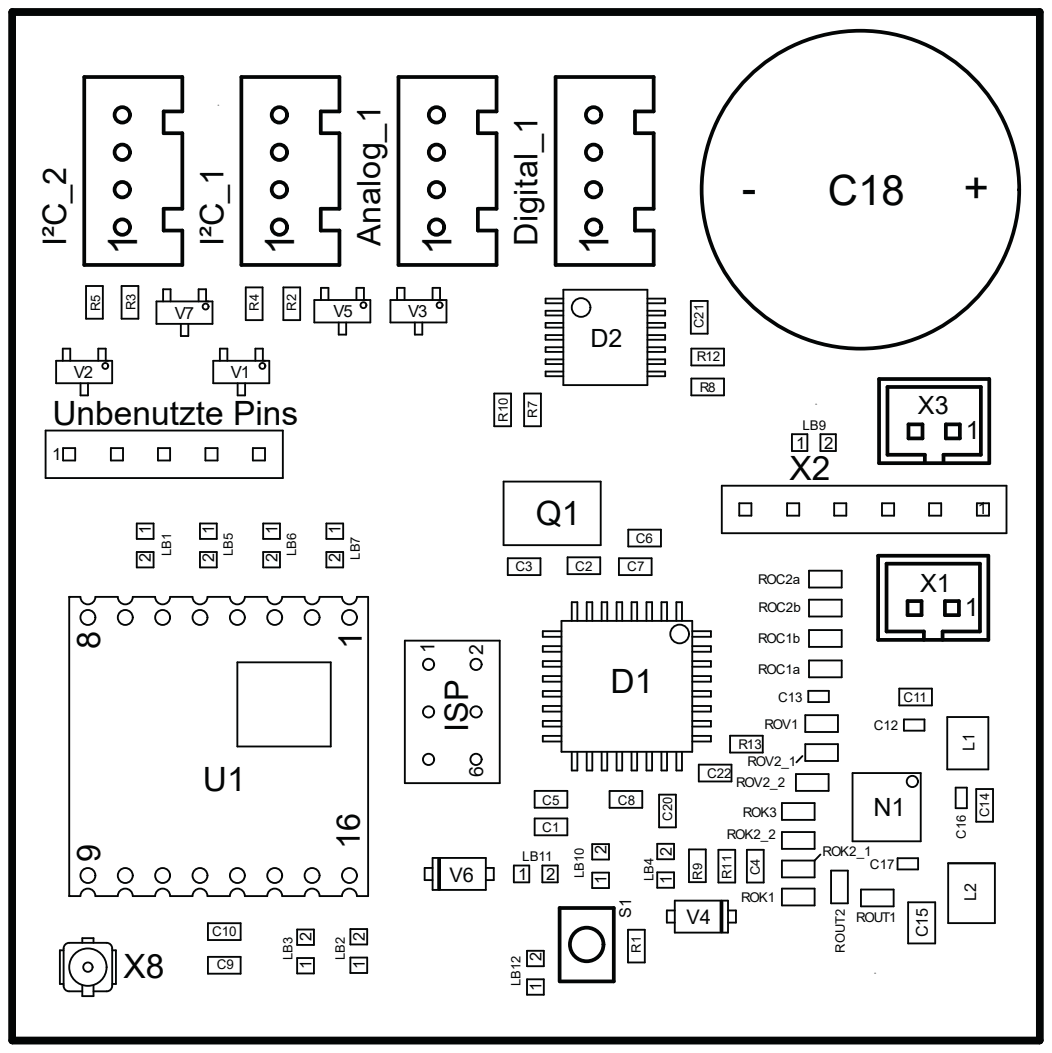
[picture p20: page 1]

gezeichnet
geprüft
Änd.Nr. | Datum | Name | geprüft | Benennung: LoRa

Format A4

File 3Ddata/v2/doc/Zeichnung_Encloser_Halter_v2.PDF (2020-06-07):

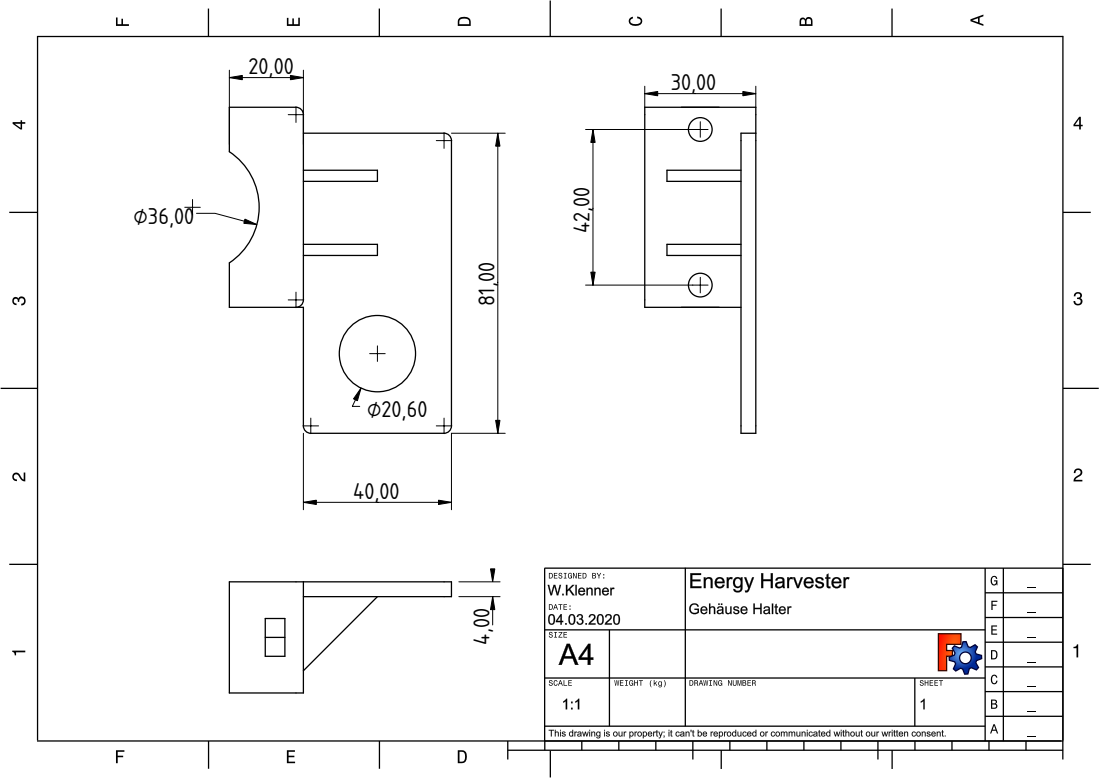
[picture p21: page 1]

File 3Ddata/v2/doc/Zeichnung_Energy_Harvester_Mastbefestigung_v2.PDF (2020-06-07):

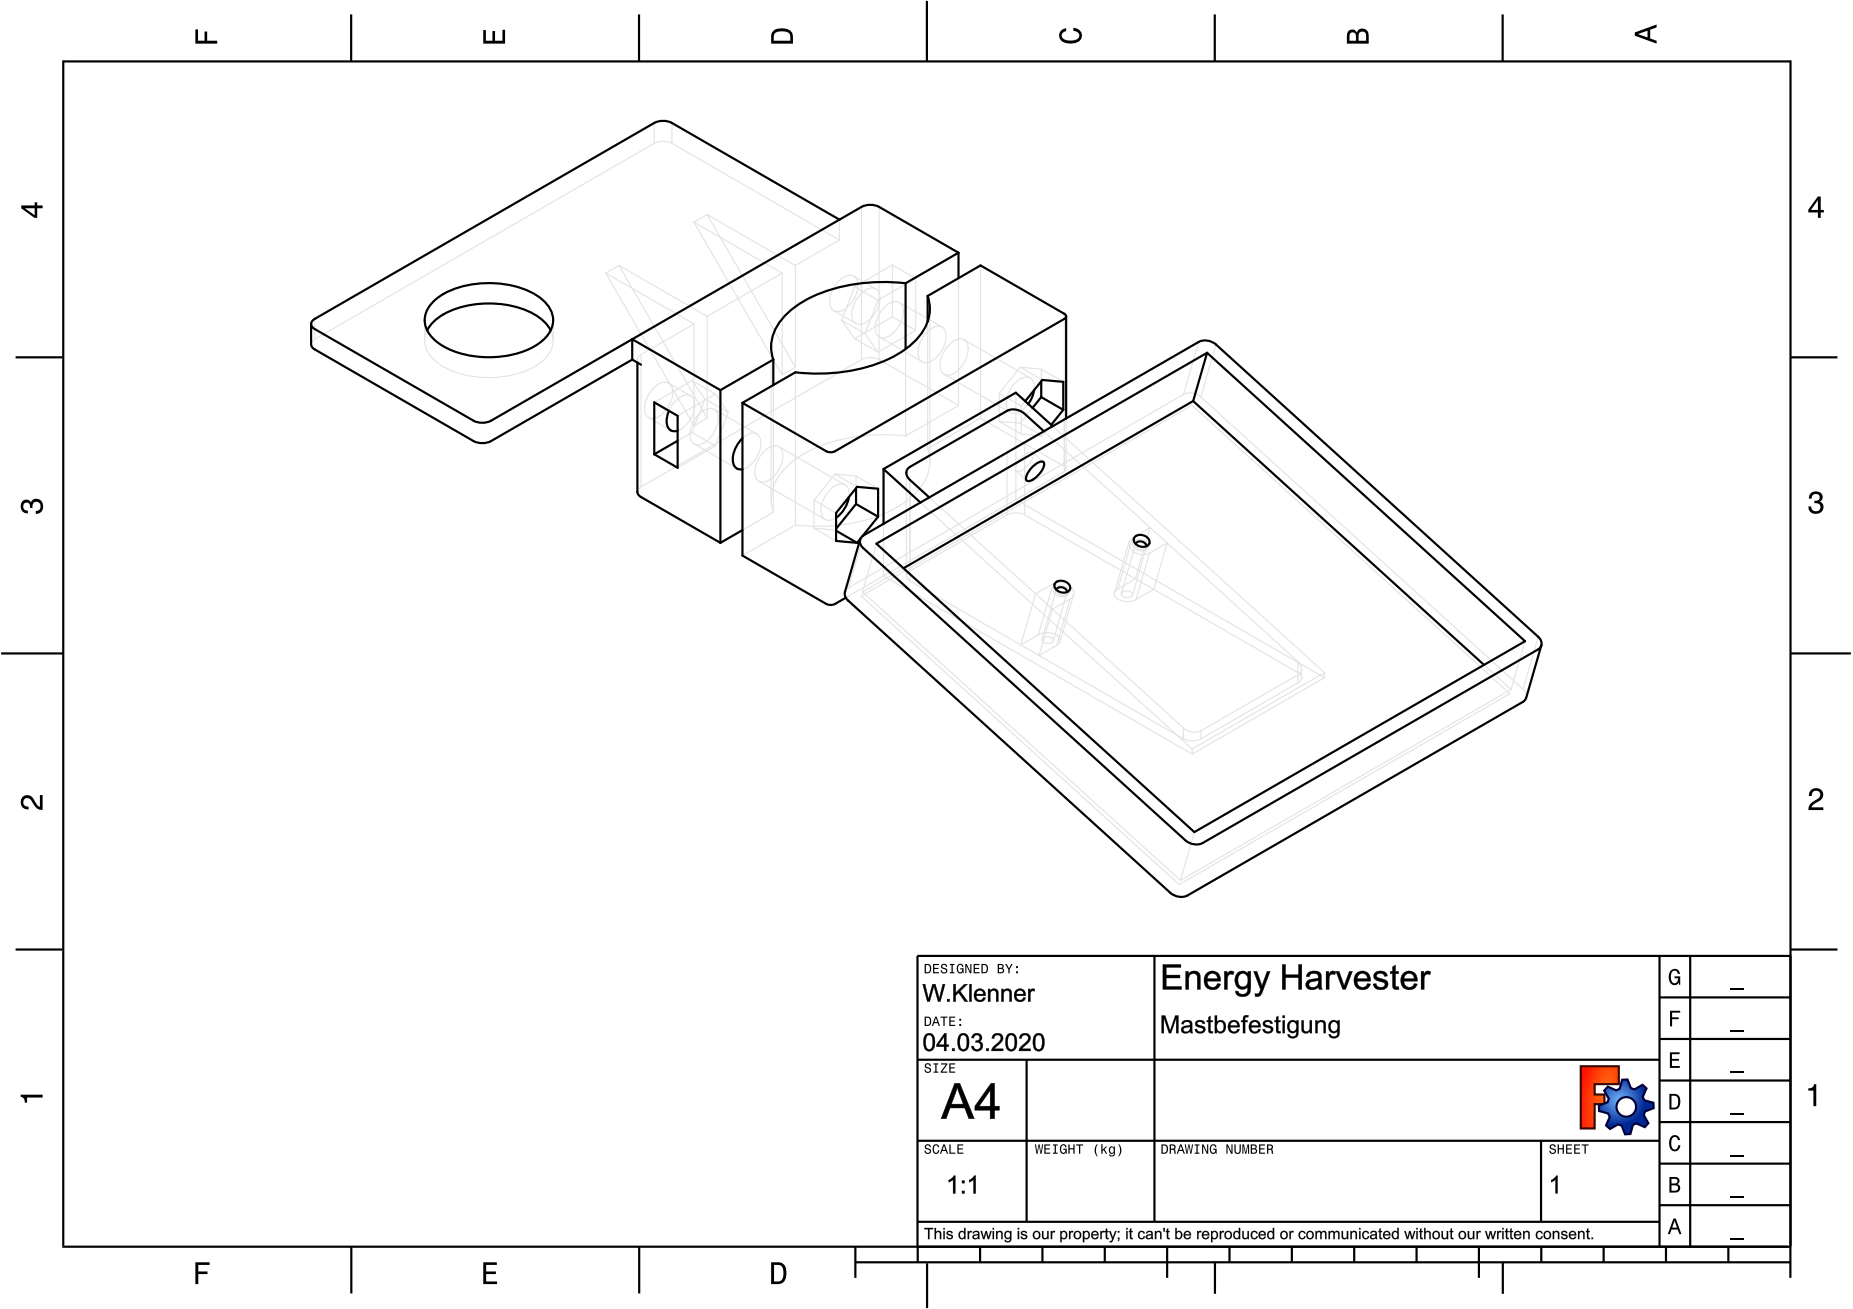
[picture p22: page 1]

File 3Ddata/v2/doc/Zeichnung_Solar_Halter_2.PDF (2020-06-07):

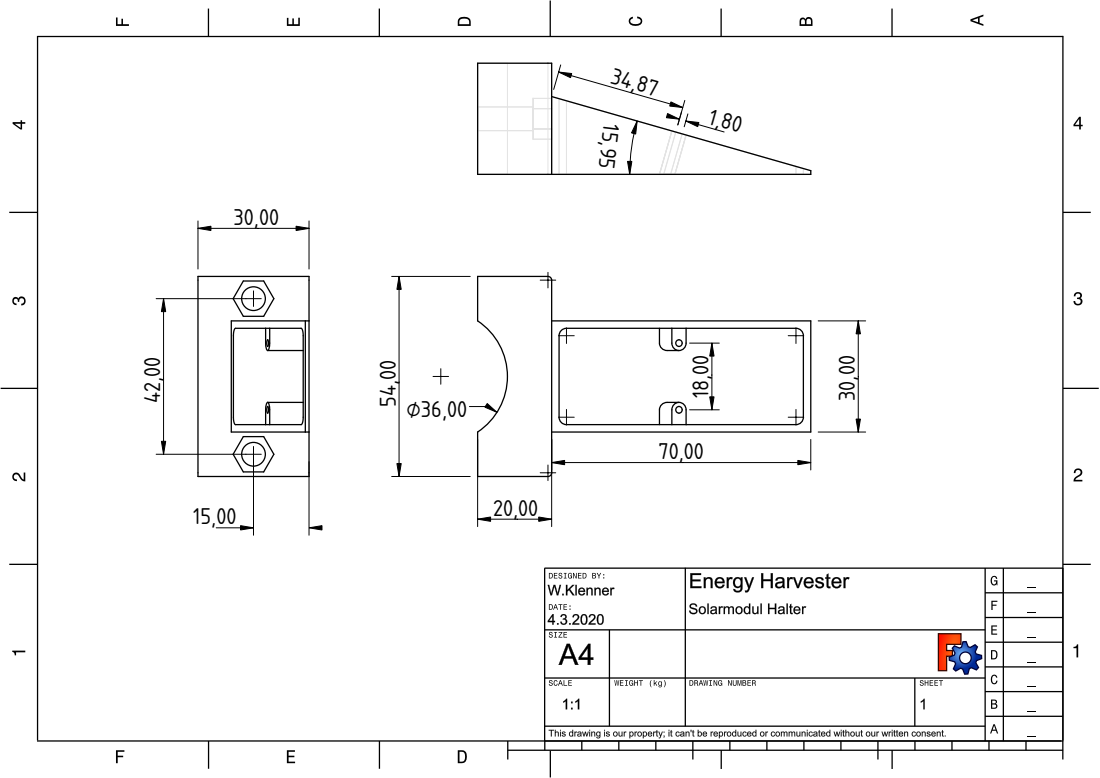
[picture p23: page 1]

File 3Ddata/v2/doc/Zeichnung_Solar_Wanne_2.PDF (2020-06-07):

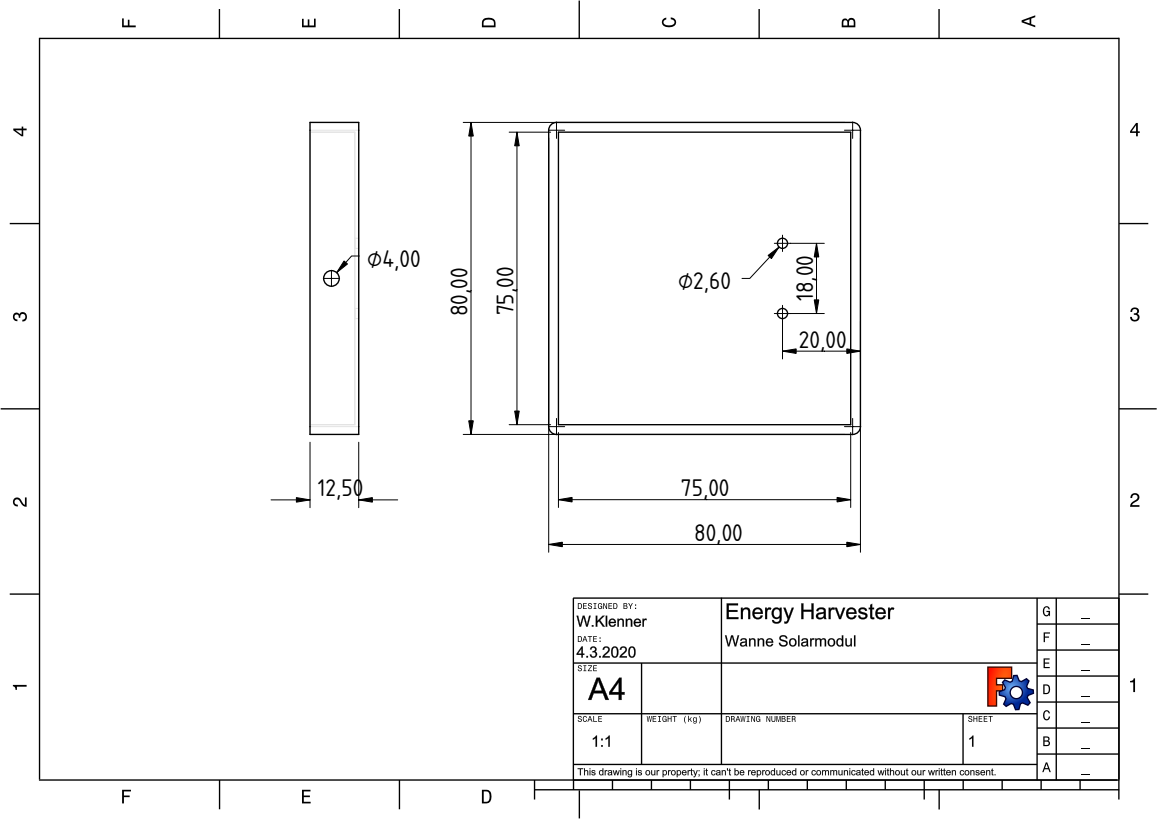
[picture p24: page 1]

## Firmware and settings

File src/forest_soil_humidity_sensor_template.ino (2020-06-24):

/*******************************************************************************
   This sketch is derived from the lmic example sketch for OTAA LoRaWAN nodes.
   The example sketch was created by Thomas Telkamp, Matthijs Kooijman and
   Terry Moore.

   The example sketch was extended and modified to run on the LoRaWAN Energy
   Harvester node (https://github.com/ablexOnGithub/energyharvester) and
   use a capacitive soil humidity sensor plus two DS18B20 temperature sensors.
   It allows for simple remote configuration per LoRa Downlink to select the index
   of the DS18B20.

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
   This uses OTAA (Over-the-air activation), where where a DevEUI and
   application key is configured, which are used in an over-the-air
   activation procedure where a DevAddr and session keys are
   assigned/generated for use with all further communication.
   
   Note: LoRaWAN per sub-band duty-cycle limitation is enforced (1% in
   g1, 0.1% in g2), but not the TTN fair usage policy (which is probably
   violated by this sketch when left running for longer)!
   
   To use this sketch, first register your application and device with
   the things network, to set or generate an AppEUI, DevEUI and AppKey.
   Multiple devices can use the same AppEUI, but each device has its own
   DevEUI and AppKey.
   
   Do not forget to define the radio type correctly in
   arduino-lmic/project_config/lmic_project_config.h or from your BOARDS.txt.
 *******************************************************************************/
#include <LowPower.h>
#include <OneWire.h>
#include <DallasTemperature.h>
#include <avr/power.h>
#include <lmic.h>
#include <hal/hal.h>
#include <SPI.h>
#include "EEPROM.h"

#define SDA_PORT PORTC
#define SDA_PIN 4 // = A4
#define SCL_PORT PORTC
#define SCL_PIN 5 // = A5

#define I2C_HARDWARE 1
#define I2C_TIMEOUT 5000
#define I2C_SLOWMODE 1

#define PIN_VCC A0

const int MAGICNUMBER = 0x55AA0001;

struct SensorConfig {
  int magicNum = MAGICNUMBER;
  byte indexAir = 0; // The index of the DS18B20 sensor put into air
  byte indexSoil = 1;  // The index of the DS18B20 sensor put into soil
  int offsetCapSoil = 0; // a signed offset value for the capacitive soil moisture measurement
  int txInterval = 120; // Transmit interval in seconds
};

// Offsets of EEPROM structures
int eeSensorConfigOffset = 0;

// Global structure for sensor configuration
SensorConfig sensConf;

OneWire  ds(3);  // on pin 3 (a 4.7K resistor is necessary)
DallasTemperature sensors(&ds);

#include <SoftWire.h>
SoftWire Wire = SoftWire();

// show debug statements; comment next line to disable debug statements
//#define DEBUG

// show development messages on console.
//#define DEVEL

// This EUI must be in little-endian format, so least-significant-byte
// first. When copying an EUI from ttnctl output, this means to reverse
// the bytes. For TTN issued EUIs the last bytes should be 0xD5, 0xB3,
// 0x70.
static const u1_t PROGMEM APPEUI[8] = { 0x00, 0x00, 0x00, 0x00, 0x00, 0x00, 0x00, 0x00 };
void os_getArtEui (u1_t* buf) {
  memcpy_P(buf, APPEUI, 8);
}

// This should also be in little endian format, see above.
static const u1_t PROGMEM DEVEUI[8] = { 0x00, 0x00, 0x00, 0x00, 0x00, 0x00, 0x00, 0x00 };
void os_getDevEui (u1_t* buf) {
  memcpy_P(buf, DEVEUI, 8);
}

// This key should be in big endian format (or, since it is not really a
// number but a block of memory, endianness does not really apply). In
// practice, a key taken from ttnctl can be copied as-is.
static const u1_t PROGMEM APPKEY[16] = { 0x00, 0x00, 0x00, 0x00, 0x00, 0x00, 0x00, 0x00, 0x00, 0x00, 0x00, 0x00, 0x00, 0x00, 0x00, 0x00 };
void os_getDevKey (u1_t* buf) {
  memcpy_P(buf, APPKEY, 16);
}

static uint8_t mydata[24];
static osjob_t sendjob;

int onPinI2C1 = 4; //PD4
int onPinI2C2 = 5; //PD5
int onPinADC = 6; //PD6

int adcVal = 0;
int sensorAddress = 0x20;

// Configure RX Callback as static function
static lmic_rxmessage_cb_t processRxData;

// Schedule TX every this many seconds (might become longer due to duty
// cycle limitations).
const unsigned TX_INTERVAL = 400; // approx. 46 ticks is a minute.
bool next = false;

// Pin mapping
const lmic_pinmap lmic_pins = {
  .nss = 10,
  .rxtx = LMIC_UNUSED_PIN,
  .rst = 9,
  .dio = {2, 7, 8},
};

void onEvent (ev_t ev) {
  Serial.print(os_getTime());
  Serial.print(": ");
  switch (ev) {
    case EV_SCAN_TIMEOUT:
#ifdef DEBUG    
      Serial.println(F("EV_SCAN_TIMEOUT"));
#endif
      break;
    case EV_BEACON_FOUND:
#ifdef DEBUG
      Serial.println(F("EV_BEACON_FOUND"));
#endif
      break;
    case EV_BEACON_MISSED:
#ifdef DEBUG
      Serial.println(F("EV_BEACON_MISSED"));
#endif
      break;
    case EV_BEACON_TRACKED:
#ifdef DEBUG
      Serial.println(F("EV_BEACON_TRACKED"));
#endif
      break;
    case EV_JOINING:
      Serial.println(F("EV_JOINING"));
      break;
    case EV_JOINED:
      Serial.println(F("EV_JOINED"));
      {
        u4_t netid = 0;
        devaddr_t devaddr = 0;
        u1_t nwkKey[16];
        u1_t artKey[16];
        LMIC_getSessionKeys(&netid, &devaddr, nwkKey, artKey);

#ifdef DEBUG
        Serial.print("netid: ");
        Serial.println(netid, DEC);
        Serial.print("devaddr: ");
        Serial.println(devaddr, HEX);
        Serial.print("artKey: ");
        for (int i = 0; i < sizeof(artKey); ++i) {
          Serial.print(artKey[i], HEX);
        }
        Serial.println("");
        Serial.print("nwkKey: ");
        for (int i = 0; i < sizeof(nwkKey); ++i) {
          Serial.print(nwkKey[i], HEX);
        }
        Serial.println("");
#endif
      }
      // Disable link check validation (automatically enabled
      // during join, but because slow data rates change max TX
      // size, we don't use it in this example.
      LMIC_setLinkCheckMode(0);
      break;
    case EV_JOIN_FAILED:
#ifdef DEBUG    
      Serial.println(F("EV_JOIN_FAILED"));
#endif
      break;
    case EV_REJOIN_FAILED:
#ifdef DEBUG    
      Serial.println(F("EV_REJOIN_FAILED"));
#endif
      break;
    case EV_TXCOMPLETE:
#ifdef DEBUG    
      Serial.println(F("EV_TXCOMPLETE (includes waiting for RX windows)"));
#endif

#ifdef DEBUG
      if (LMIC.txrxFlags & TXRX_ACK)
        Serial.println(F("Received ack"));
      if (LMIC.dataLen) {
        Serial.print(F("Received "));
        Serial.print(LMIC.dataLen);
        Serial.println(F(" bytes of payload"));
      }
#endif
      if (!LMIC.dataLen) {
        goToSleep();
      }
      // Schedule next transmission
      next = true;
      break;
    case EV_LOST_TSYNC:
#ifdef DEBUG    
      Serial.println(F("EV_LOST_TSYNC"));
#endif
      break;
    case EV_RESET:
#ifdef DEBUG    
      Serial.println(F("EV_RESET"));
#endif
      break;
    case EV_RXCOMPLETE:
      // data received in ping slot
#ifdef DEBUG      
      Serial.println(F("EV_RXCOMPLETE"));
#endif
      break;
    case EV_LINK_DEAD:
#ifdef DEBUG    
      Serial.println(F("EV_LINK_DEAD"));
#endif
      break;
    case EV_LINK_ALIVE:
#ifdef DEBUG
      Serial.println(F("EV_LINK_ALIVE"));
#endif      
      break;
    case EV_TXSTART:
#ifdef DEBUG
      Serial.println(F("EV_TXSTART"));
#endif
      break;
    default:
#ifdef DEBUG
      Serial.print(F("Unknown event: "));
      Serial.println((unsigned) ev);
#endif
      break;
  }
}

void writeI2CRegister8bit(int addr, int value) {
  Wire.beginTransmission(addr);
  Wire.write(value);
  Wire.endTransmission();
}

unsigned int readI2CRegister16bit(int addr, int reg) {
  Wire.beginTransmission(addr);
  Wire.write(reg);
  Wire.endTransmission();
  delay(100);
  Wire.requestFrom(addr, 2);
  unsigned int t = Wire.read() << 8;
  t = t | Wire.read();
  return t;
}

unsigned int readI2CRegister8bit(int addr, int reg) {
  Wire.beginTransmission(addr);
  Wire.write(reg);
  Wire.endTransmission();
  delay(100);
  Wire.requestFrom(addr, 1);
  unsigned int t = Wire.read();
  return t;
}

void do_send(osjob_t* j) {
  // Check if there is not a current TX/RX job running
  if (LMIC.opmode & OP_TXRXPEND) {
#ifdef DEBUG
    Serial.println(F("OP_TXRXPEND, not sending"));
#endif
  } else {
    // Prepare upstream data transmission at the next possible time.
    switchSensorPowerOn();
    switchI2COn();
    getMeasurements();
    switchSensorPowerOff();
    switchI2COff();
    LMIC_setTxData2(1, mydata, sizeof(mydata), 0);
#ifdef DEBUG
    Serial.println(F("Packet queued"));
#endif
  }
  // Next TX is scheduled after TX_COMPLETE event.
}

void getMeasurements() {
  int lumi, tempr, capa;
  int temp_ds1, temp_ds2;
  int vcc;

  sensors.requestTemperatures();
  temp_ds1 = (int) ( sensors.getTempCByIndex(sensConf.indexAir) * 10.0);
  temp_ds2 = (int) ( sensors.getTempCByIndex(sensConf.indexSoil) * 10.0);
  vcc = (int)(getVcc() * 100.0);
  writeI2CRegister8bit(sensorAddress, 6); //reset Humidity sensor
  delay(5);
  writeI2CRegister8bit(sensorAddress, 0x03); //request light measurement
  delay(200);
  lumi = readI2CRegister16bit(sensorAddress, 0x04); //read light register
#ifdef DEVEL
  Serial.print(F("\nLight: "));
  Serial.println(lumi); //light measurement
#endif
  tempr = readI2CRegister16bit(sensorAddress, 0x05); //temperature register
#ifdef DEVEL
  Serial.print(F("Temperature: "));
  Serial.println(tempr / 10.0); //temperature register
#endif
  capa = readI2CRegister16bit(sensorAddress, 0x00); //read capacitance register
#ifdef DEVEL
  Serial.print(F("Soil Moisture Capacitance: "));
  Serial.println(capa); // capacitance register
  Serial.print(F("Vcc level (0.01V/digit):"));
  Serial.println(vcc);
#endif
  writeI2CRegister8bit(sensorAddress, 0x08); //go to sleep Humidity sensor
  mydata[0] = 0x01; // data channel 1
  mydata[1] = 0x67; // data type temperature
  mydata[2] = (tempr >> 8) & 0xFF;
  mydata[3] = tempr & 0xFF;
  mydata[4] = 0x02; // data channel 2
  mydata[5] = 0x67; // data type temperature
  mydata[6] = (temp_ds1 >> 8) & 0xFF;
  mydata[7] = temp_ds1 & 0xFF;
  mydata[8] = 0x03; // data channel 3
  mydata[9] = 0x67; // data type temperature
  mydata[10] = (temp_ds2 >> 8) & 0xFF;
  mydata[11] = temp_ds2 & 0xFF;
  mydata[12] = 0x04; // data channel 4
  mydata[13] = 0x02; // data type analog input 2 bytes
  mydata[14] = (capa >> 8) & 0xFF;
  mydata[15] = capa & 0xFF;
  mydata[16] = 0x05; // data channel 5
  mydata[17] = 0x65; // data type illumination
  mydata[18] = (lumi >> 8) & 0xFF;
  mydata[19] = lumi & 0xFF;
  mydata[20] = 0x06; // data channel 6
  mydata[21] = 0x02; // data type analog input 2 bytes
  mydata[22] = (vcc >> 8) & 0xFF;
  mydata[23] = vcc & 0xFF;
}

float getVcc() {
  int sensorValue;
  switchAnalogOn();
  sensorValue = analogRead(PIN_VCC);
  switchAnalogOff();
  return (((sensorValue + 0.5) * 3.85) / 1024.0); //1.1V * 3.5 = 3.85
}

void switchSensorPowerOff() {
  digitalWrite(onPinI2C1, LOW);
  delay(10); // Set delay of 10ms before switching to Input
  pinMode(onPinI2C1, INPUT);
}

void switchSensorPowerOn() {
  pinMode(onPinI2C1, OUTPUT);
  digitalWrite(onPinI2C1, HIGH);
}

void switchAnalogOn() {
  pinMode(PD6, OUTPUT);
  digitalWrite(PD6, HIGH);
}

void switchAnalogOff() {
  pinMode(PD6, OUTPUT);
  digitalWrite(PD6, LOW);
}

void switchI2COn() {
  pinMode(A4, OUTPUT);
  pinMode(A5, OUTPUT);
  power_twi_enable();
}

void switchI2COff() {
  pinMode(A4, INPUT);
  pinMode(A5, INPUT);
  power_twi_disable();
}

void readEEConfig() {
  EEPROM.get(eeSensorConfigOffset, sensConf);  
}

void writeEEConfig(bool doInit = false) {
  if (doInit == true) {
    sensConf.magicNum = MAGICNUMBER;
    sensConf.indexAir = 0; // The index of the DS18B20 sensor put into air
    sensConf.indexSoil = 1;  // The index of the DS18B20 sensor put into soil
    sensConf.offsetCapSoil = 0; // a signed offset value for the capacitive soil moisture measurement
    sensConf.txInterval = 120; // Transmit interval in seconds
  }
  EEPROM.put(eeSensorConfigOffset, sensConf);
}


static void processRxData(void *pUserData, uint8_t port, const uint8_t *pMsg, size_t nMsg) {
  int cnt = 0;

  // ignore mac messages
  if (port == 0) {
    return;
  }
#ifdef DEBUG
  Serial.println(F("Processing Downlink data"));
#endif
  // Only downlink messages with port == 1 are evaluated
  if (port == 1) {
    for (int i = 0; i < nMsg; i++) {
      cnt = pMsg[i];
      i++;
      switch (cnt) {
        case 0x01:
          // Write index of Air temp sensor
          sensConf.indexAir = pMsg[i];
          break;
        case 0x02:
          // Write index of Soil temp sensor (18B20)
          sensConf.indexSoil = pMsg[i];
          break;
        case 0x03:
          // Write offset of soil moisture sensor
          sensConf.offsetCapSoil = (int) ((pMsg[i] << 8) + pMsg[i + 1]);
          i++;
          break;
        case 0x04:
          // Write TX interval = Minutes (roughly)
          sensConf.txInterval = (int) (((pMsg[i] << 8) + pMsg[i + 1])*60);
          i++;
        default:
          break;
      }
    }
    // Write EEPROM config values
    writeEEConfig();
  }
}

void setup() {
  Serial.begin(38400);
  Serial.println(F("Starting"));

  // Set reference voltage to internal 1.1V
  analogReference(INTERNAL);

  // Read EEPROM config values
  readEEConfig();
  if (sensConf.magicNum != MAGICNUMBER) {
    writeEEConfig(true);
  }

  // register a callback for downlink messages.
  LMIC_registerRxMessageCb(processRxData, NULL);

  // Start OneWire sensor init
  sensors.begin();

  // Measure reference Vcc against internal reference voltage 1.1V
  Serial.print(F("Current Vcc level:"));
  Serial.println(getVcc());

  switchSensorPowerOn();
  switchI2COn();
  Wire.begin();
  Serial.println(F("Starting humidity sensor"));
  writeI2CRegister8bit(0x09, 6); //reset Humidity sensor
  delay(1000);
  Serial.print(F("I2C Soil Moisture Sensor Address: "));
  Serial.println(sensorAddress, HEX);
  Serial.print(F("Sensor Firmware version: "));
  Serial.println(readI2CRegister8bit(sensorAddress, 0x07), HEX);
  Serial.println();
  writeI2CRegister8bit(sensorAddress, 0x08); //go to sleep Humidity sensor

  // Print OneWire temperature values
  Serial.print(F("No. of sensors found on I2C: "));
  Serial.println(sensors.getDS18Count());
  sensors.requestTemperatures();
  Serial.print(F("18B20 Temperature measurements:\nIndex 0 = "));
  Serial.print(sensors.getTempCByIndex(0));
  Serial.print(F("°C\nIndex 1 = "));
  Serial.print(sensors.getTempCByIndex(1));
  Serial.println("°C");

  // LMIC init
  os_init();
  // Reset the MAC state. Session and pending data transfers will be discarded.
  LMIC_reset();
  LMIC_setClockError(MAX_CLOCK_ERROR * 1 / 100);
  // Start job (sending automatically starts OTAA too)
  do_send(&sendjob);
}

void goToSleep() {
  extern volatile unsigned long timer0_overflow_count;
  int sleepcycles = sensConf.txInterval / 8;  // calculate the number of sleepcycles (8s) given the TX interval in seconds
  Serial.println(F("Going to sleep!"));
#ifdef DEBUG
  Serial.print(sleepcycles);
  Serial.println(F(" cycles of 8 seconds"));
#endif
  Serial.flush(); // give the serial print chance to complete
  power_usart0_disable();
  power_spi_disable();
  for (int i = 0; i < sleepcycles; i++) {
    // Enter power down state for 8 s with ADC and BOD module disabled
    LowPower.powerDown(SLEEP_8S, ADC_OFF, BOD_OFF);
    // LMIC uses micros() to keep track of the duty cycle, so
    // hack timer0_overflow for a rude adjustment:
    cli();
    timer0_overflow_count += 8 * 64 * clockCyclesPerMicrosecond();
    sei();
  }
  power_spi_enable();
  power_usart0_enable();
#ifdef DEBUG
  Serial.println(F("Sleep complete"));
#endif
}

void loop() {
  if (next == false) {
    os_runloop_once();
  } else {
    next = false;
    // Start job
    do_send(&sendjob);
  }
}

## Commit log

2019-12-24 Initial commit with a base set of project files
    [BOM_LoRaWAN_EnergyHarvester.xlsx, bq25505(70_Design_Help_V1_3.xlsx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]
2019-12-29 Work in progess commit of README and a new calculation sheet for a Supercap only mode.
    [bq25505_Bauteilberechnung_SuperCap_5V4_Buck_3V3_MPTT_Solar.xlsx]
2020-01-10 Rework of Supercap calculations and adjustments to documentation accordingly
    [bq25505_Bauteilberechnung_SuperCap_5V4_Buck_3V3_MPTT_Solar.xlsx, bq25505_Bauteilberechnung_SuperCap_5V_Buck_3V3_MPTT_Solar.xlsx]
2020-01-10 Fixed resistor table
2020-01-28 Added some configuration info for IDE board configuration
2020-02-03 More explanation on the current measurement.
2020-03-01 Added 3D printing files for mast mount of harvester. readme adjusted.
    [Solar_mount1.stl, eharvester_mount.stl, enclosure_back_mount.stl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]
2020-06-07 Restructured 3D data subfolder to store multiple versions
    [Solar_mount1.stl, eharvester_mount.stl, enclosure_back_mount.stl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]
2020-06-07 The v2 of the eHarvester mount was done by TTN Stuttgart community colleague Wolfgang. These are his comments on the changes: beigefügte Konstruktionen basieren auf den Entwürfen von Tobias v.K-S. Di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
    [eharvester_mount.stl, encloser_halter_v2.FCStd, encloser_halter_v2.stl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]
2020-06-12 Adding a photo of the 3D printed parts.
2020-06-12 Photo of 3D printed parts assembled.
2020-06-12 Extended Energy Harvester Arduino template with support for DS18B20 temp sensors and simple remote configuration per LoRaWAN downlink.
2020-06-23 Extended forest sensor template to use EEPROM for storing configuration and also process Downlink LoRaWAN messages. Inside the downlink messages there are parameters for Sleep time adjustment, sensor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
    [forest_soil_humidity_sensor_template.ino]
2020-06-24 Bugfix: confused lsh with rsh
    [forest_soil_humidity_sensor_template.ino]
